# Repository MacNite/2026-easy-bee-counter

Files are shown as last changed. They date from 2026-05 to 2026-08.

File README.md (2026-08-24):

# Bee Counter Redesign — Full Specification
### Single PCB + 3D Printed Housing, reported over BLE to HiveHub

A redesign of the [2019-easy-bee-counter](https://github.com/hydronics2/2019-easy-bee-counter)
by hydronics2: 24 entrance gates, 48 reflective IR sensors read through I²C
port expanders, and an always-on ESP32-C6 doing the counting and reporting
totals over BLE.

> **Status:** the PCB (`PCB_files/easy-bee-counter-2026.kicad_*`) and the
> ESP32-C6 firmware (`Firmware/`) are implemented. The 3D-printed housing
> (Section 5) is the remaining mechanical work.

---

## 1. System Overview

The **ESP32-C6 mini** runs always-on as a dedicated bee counter and advertises
as a connectable BLE peripheral. A HiveHub wakes roughly every 10 minutes,
connects, reads one JSON characteristic of lifetime totals and disconnects,
combining the counts with weight/timestamp data before logging and transmitting.

```
[HiveHub ESP32] ←——— BLE/GATT ———→ [ESP32-C6 mini]
  wakes every ~10 min                always-on, ~15 mA
  RTC, SD, WiFi, scale               bee counting, 3× MCP23017 (I²C)
```

The counter's own I²C bus (`Wire`, silk D4 = GPIO22 SDA / silk D5 = GPIO23 SCL) is used only to reach
the 3× MCP23017 port expanders.

> **The wired HiveScale link is gone.** Earlier revisions ran the C6's second
> I²C controller as a permanent slave at 0x30, serving a register map to a
> HiveScale polling over J1 — and the firmware for it has been removed, because
> HiveHub reads counters over BLE only and dropped its wired client. Sections
> below still describe the J1 connector and its cable, since both are physically
> on the PCB; no firmware brings that bus up, so populating them is optional.

---

## 2. Complete Bill of Materials

### 2.1 Microcontroller

| # | Component | Qty | Notes |
|---|---|-----|---|
| 1 | Seeed XIAO ESP32C6 (Seeed 113991054) | 1 | Always-on bee counter MCU. ~15 mA active, 3.3 V logic, USB-C. Two hardware I²C controllers. **Silk D0..D10 ≠ GPIO numbers** — see `Firmware/include/pins.h` |

### 2.2 I/O Expansion (replaces all 6× 74HC165)

| # | Component | Qty | Notes |
|---|---|-----|---|
| 2 | MCP23017-E/SP (DIP-28) | 3 | 16 inputs each = 48 total. I²C addresses 0x20, 0x21, 0x22 (on bus 0) |

### 2.3 IR Sensors

| # | Component | Qty | Notes |
|---|---|-----|---|
| 3 | QRE1113 or ITR8307 reflectance sensor | 48 | 2 per gate × 24 gates. ITR8307 from LCSC is cheaper (~€0.13 each) |

### 2.4 MOSFETs (IR LED switching)

| # | Component | Qty | Notes |
|---|---|-----|---|
| 4 | IRLB8721PbF N-channel MOSFET (TO-220) | 3 | 3.3 V gate-safe. One per MCP23017: Q1 = LED_BANK_1 (gates 00..07), Q2 = LED_BANK_2 (gates 10..17), Q3 = LED_BANK_3 (gates 20..27). Individually switchable at runtime — see [Power Budget](#6-power-budget) |

### 2.5 Resistors

| # | Component | Qty | Notes |
|---|---|-----|---|
| 5 | 22 Ω bussed SIP resistor (9-pin, 8R) | 3 | IR LED current limiting (2 LEDs in series per gate) |
| 6 | 100 kΩ bussed SIP resistor (9-pin, 8R) | 6 | Sensor pull-up resistors (1 per MCP23017 input, to +3.3 V) |
| 7 | 10 kΩ resistor (through-hole) | 6 | MOSFET gate pull-downs (3×), MCP23017 RESET pull-ups (3×) |
| 8 | 4.7 kΩ resistor (through-hole) | 2 | Bus 0 I²C pull-ups (SDA + SCL to 3.3 V), R4/R5 |

> J1 (the retired HiveScale link) does **not** need on-board pull-ups — those were
> provided by the HiveScale-side I²C network.

### 2.6 Capacitors

| # | Component | Qty | Notes |
|---|---|-----|---|
| 9 | 100 nF ceramic capacitor (through-hole) | 6 | Decoupling, 1 per MCP23017 VDD pin + 3 spare |
| 10 | 10 µF electrolytic capacitor | 1 | Bulk decoupling on 3.3 V rail |

### 2.7 Connectors

| # | Component | Qty | Notes |
|---|---|-----|---|
| 11 | 4-pin JST-PH or screw terminal (I²C bus 1 + GND + 3.3 V) | 1 | Connection cable to HiveScale (J1) |
| 12 | 2-pin screw terminal | 1 | 3.3 V power input from HiveScale |
| 13 | USB-C connector (on C6 mini board) | — | For firmware flashing / serial only |

### 2.8 PCB & Housing

| # | Component | Qty | Notes |
|---|---|-----|---|
| 14 | Custom PCB (single board, black substrate) | 1 | Designed in KiCad (`PCB_files/`). Order black. See Section 4 |
| 15 | 3D printed top baffle / housing | 1 | Carbon-filled PETG or ASA. See Section 5 |
| 16 | M2×6 screws | 8 | PCB to housing standoffs |
| 17 | M2 brass heat-set inserts | 8 | Into 3D printed housing |

---

## 3. Wiring & Connection Map

### 3.1 I²C Buses

This board uses **two separate I²C buses**, one per controller:

**Bus 0 (`Wire`) — MCP23017 master bus.** Silk D4 = GPIO22 = SDA, silk D5 = GPIO23 = SCL. On-board
4.7 kΩ pull-ups (R4/R5) to 3.3 V.

```
XIAO D4 = GPIO22 (SDA) ——+——————+——————+——— 4.7 kΩ ——→ 3.3 V
                        |      |      |
                      MCP1   MCP2   MCP3
                      0x20   0x21   0x22

XIAO D5 = GPIO23 (SCL) ——+——————+——————+——— 4.7 kΩ ——→ 3.3 V
```

**J1 (silk D2 / D3 = GPIO2 / GPIO21) — the retired HiveScale slave bus.** The pads and traces
are on the board, and pull-ups were supplied by the HiveScale side. **No current
firmware brings this controller up**, so the pins stay inputs and populating J1
is optional — see the note in Section 1.

> **Note on the schematic net names:** the schematic labels the master bus nets
> "/SDA" and "/SDC" (a typo for SCL), and the LED-bank nets "/GPIO4" / "/GPIO5"
> / "/GPIO6". Those are just net *names* — physically the LED banks are driven
> from silk D8 = GPIO19, D9 = GPIO20 and D10 = GPIO18. U5 is a Seeed XIAO ESP32C6, whose silk
> numbers are **not** its GPIO numbers; see `Firmware/include/pins.h` for the
> authoritative map.

### 3.2 MCP23017 Wiring (repeat for each of the 3 chips, all on bus 0)

| MCP23017 Pin | Connection | Notes |
|---|---|---|
| 9 (VDD) | 3.3 V | Add 100 nF ceramic cap to GND nearby |
| 10 (VSS) | GND | |
| 12 (SCL) | Bus 0 SCL (silk D5 = GPIO23) | |
| 13 (SDA) | Bus 0 SDA (silk D4 = GPIO22) | |
| 15 (A0) | GND / 3.3 V | Address bit 0 (see table below) |
| 16 (A1) | GND / 3.3 V | Address bit 1 |
| 17 (A2) | GND / 3.3 V | Address bit 2 |
| 18 (RESET) | 3.3 V via 10 kΩ | Tie high; no active reset needed |
| 21–28 (GPA0–7) | IR sensor outputs (inner sensors) | 8 sensors per chip |
| 1–8 (GPB0–7) | IR sensor outputs (outer sensors) | 8 sensors per chip |

**Address configuration:**

| Chip | I²C Address | A2 | A1 | A0 | Gates |
|---|---|----|----|----|----|
| MCP1 (U2) | 0x20 | GND | GND | GND | 00–07 |
| MCP2 (U3) | 0x21 | GND | GND | 3.3 V | 10–17 |
| MCP3 (U4) | 0x22 | GND | 3.3 V | GND | 20–27 |

> Gate tags have gaps (08, 09, 18, 19, 28, 29 are skipped) to keep the
> per-chip pin→gate map clean; there are 24 physical gates indexed 0..23
> internally.

### 3.3 IR Sensor Wiring (per sensor pair, 24× repeated)

Each gate has 2 sensors — one "inner" (towards hive), one "outer" (towards field).

```
QRE1113 pin 1 (Anode / LED+)   ——→ LED string common (+ / 3.3 V via 22 Ω)
QRE1113 pin 2 (Cathode / LED-) ——→ MOSFET Drain (bank rail)
QRE1113 pin 3 (Collector)      ——→ MCP23017 GPIO input pin + 100 kΩ pull-up to 3.3 V
QRE1113 pin 4 (Emitter)        ——→ GND
```

Logical convention in firmware: **sensor reads LOW = beam reflected/blocked
(bee in beam); HIGH = clear or LEDs off.**

### 3.4 MOSFET Wiring (IRLB8721PbF, 3× identical — one per MCP23017)

| IRLB8721 Pin | Connection |
|---|---|
| Gate (pin 1) | Bank enable GPIO from the table below, + 10 kΩ pull-down to GND |
| Drain (pin 2) | IR LED cathode strings for that bank |
| Source (pin 3) | GND |

| FET | Bank | Gates | XIAO silk | GPIO | Schematic net |
|---|---|---|---|---|---|
| Q1 | LED_BANK_1 | 00..07 (U2 @ 0x20) | D8  | GPIO19 | /GPIO4 |
| Q2 | LED_BANK_2 | 10..17 (U3 @ 0x21) | D9  | GPIO20 | /GPIO5 |
| Q3 | LED_BANK_3 | 20..27 (U4 @ 0x22) | D10 | GPIO18 | /GPIO6 |

Driving the gate HIGH turns that bank's IR emitters ON.

### 3.5 HiveScale I²C Connection Cable (bus 1, connector J1)

4-wire cable between HiveScale and bee counter PCB:

| Wire | Signal |
|---|---|
| Red | 3.3 V (from HiveScale to power the C6 + MCP23017s) |
| Black | GND |
| Yellow | SDA (silk D2 = GPIO2) |
| Blue | SCL (silk D3 = GPIO21) |

This cable served the retired wired link and is not needed for a BLE counter;
the board only needs 3.3 V and GND. The MCP23017s live on their own bus and were
never visible over J1 in any case.

---

## 4. PCB Dimensions & Layout

### 4.1 Target Dimensions

Based on standard Langstroth 10-frame hive (476 mm internal entrance width):

| Dimension | Value | Notes |
|---|---|---|
| PCB length | 375 mm | Covers full entrance, leaving margin each side for housing walls |
| PCB width | 40 mm | Enough for components + connector |
| Gate pitch | 15.6 mm | 375 mm / 24 gates. Each gate ~12 mm clear opening + 3.6 mm divider wall |
| Sensor pair spacing | 8 mm | Inner-to-outer sensor distance within one gate |

**Note for European Zander/Deutsch Normal hives:** entrance width is typically 370 mm — adjust PCB length accordingly.

### 4.2 Component Placement

```
[USB-C]  [C6 mini]  [MCP1]  [MCP2]  [MCP3]  [J1 I²C connector]
                    ← electronics zone, left end →

← 24 sensor pairs spread across the remaining length →

Top edge: inner sensors (facing hive interior)
Bottom edge: outer sensors (facing landing board)
```

- ESP32-C6 and MCP23017s cluster at the left end of the PCB
- Sensor pairs run along the full length
- Q1/Q2 MOSFETs near the sensor zone centre with thermal via to bottom copper pour
- Keep the MCP I²C traces short; keep the J1 routing away from the MCP bus
- 100 nF decoupling caps placed directly adjacent to each MCP23017 VDD pin

---

## 5. 3D Printed Housing Specification

### 5.1 Material

| Property | Requirement |
|---|---|
| Material | Carbon-filled PETG (e.g. Prusament PETG CF) or ASA |
| Color | Black (carbon content ensures genuine IR opacity at 950 nm) |
| Layer height | 0.2 mm or finer for gate walls |
| Infill | 40%+ for structural rigidity |

Do NOT use standard black PLA or standard black PETG — most black dyes are IR-transparent at 950 nm. Carbon-filled variants are the exception.

### 5.2 Housing Parts

**Part 1 — Bottom tray** (holds PCB):
- Internal width: PCB width + 2 mm clearance
- Internal length: PCB length + 2 mm clearance
- Depth: 12 mm (enough for tallest through-hole component)
- 4 M2 standoff bosses at corners, 3 mm proud of floor
- Cable exit slot at left end for I²C cable

**Part 2 — Top baffle** (replaces the original second PCB):
- Same footprint as bottom tray
- 24 channel slots cut through, matching sensor pair positions
- Channel slot width: 12 mm (bee passage width)
- Channel slot height (depth of baffle): 10 mm
- Divider wall thickness between channels: 3.6 mm
- Snap or M2 screw attachment to bottom tray (4 points)
- Landing ramp angle on outer face: 15° downward slope toward hive entrance

### 5.3 Gate Geometry

```
Top view of one gate channel:
┌────────────────────────┐
│  ←── 12 mm ──→         │  ← bee passage
│  [outer sensor]         │  ← facing landing board
│          ↕ 8 mm         │
│  [inner sensor]         │  ← facing hive
└────────────────────────┘
     ← 3.6 mm wall →
```

Sensors face upward from the bottom PCB into the channel. The black baffle absorbs any IR not reflected by a bee.

---

## 6. Power Budget

| Component | Current | Count | Total |
|---|---|---|---|
| ESP32-C6 mini (active, BLE advertising) | 15 mA | 1 | 15 mA |
| MCP23017 (active) | 1 mA | 3 | 3 mA |
| Quiescent leakage | — | — | ~1 mA |
| **Electronics subtotal** | | | **~19 mA** |
| IR emitters, all banks lit (peak) | ~20–40 mA/gate | 24 gates | **~0.5–1.0 A** |
| IR emitters, pulsed at 35 % duty (average) | | | **~170–350 mA** |
| HiveScale ESP32 (sleep) | ~0.05 mA | 1 | 0.05 mA |
| HiveScale ESP32 (awake, ~10 min cycle) | 80 mA × 30 s / 600 s | 1 | ~4 mA avg |

**The emitters are the power budget.** Each gate drives two IR LEDs in series
through a 22 Ω ballast off the 3.3 V rail — roughly (3.3 − 2·V_f)/22, i.e. tens
of milliamps per gate — and the pulsed sampler lights all three banks together
for the settle+read window of every 5 ms poll. Everything else on the board
together is under 20 mA, an order of magnitude below. The per-gate figure
depends on the actual LED forward voltage; **measure it on an assembled board**
before sizing a panel or a pack, rather than trusting the range above.

Three things follow, and all three are implemented:

* **Pulsed emitters** (`LedMode::AUTO`, the default since the 2026-06 revision)
  cut the duty cycle from 100 % to ~35 %. Raising `POLL_INTERVAL_MS` lowers it
  proportionally. There is no `CMD_LEDS_OFF` — that was an I²C command on the
  wired link, which no longer exists; the bench overrides are the `-DIR_DEBUG`
  console's `1`/`0`/`a` keys.
* **Night mode** parks the emitters entirely through the hours honey bees do not
  fly, on request from HiveHub. Over an 8–12 h night that is the difference
  between the counter fitting an off-grid budget and not. See
  [`docs/ble-mode.md`](docs/ble-mode.md#night-mode-the-control-characteristic) —
  including why it is *not* implemented as deep sleep.
* **Per-bank enables** switch the three MOSFETs individually, so an entrance
  narrower than 24 gates costs only the banks it uses. Measured on an assembled
  board, at 3.3 V:

  | Banks enabled | Gates counted | Draw |
  |---|---|---|
  | 1 | 8 | ~0.14 A |
  | 2 | 16 | ~0.22 A |
  | 3 (default) | 24 | ~0.30 A |

  Roughly 80 mA per bank on top of a ~60 mA floor. All three are enabled unless
  HiveHub says otherwise (three checkboxes per device in its dashboard), and a
  counter that resets comes back with all three on. It composes with night mode
  rather than competing with it. See
  [`docs/ble-mode.md`](docs/ble-mode.md#emitter-banks-the-other-power-control).

Add solar for indefinite runtime.

---

## 7. BLE Data Handoff

The counter is a connectable BLE peripheral. The canonical definition of the
GATT contract lives in [`docs/ble-mode.md`](docs/ble-mode.md); this is a summary.

- Advertises as `HiveTraffic-AB:12` — the product name suffixed with the last
  two bytes of the counter's own BLE address, so several counters in range are
  distinct rows in a scan list. HiveHub connects by the MAC paired in its
  portal and never matches on the name.
- One service, `8e8b0101-7a1c-4b9e-9a2f-1d6e0b9c1a01`, holding a READ
  measurement characteristic, a READ/WRITE control characteristic (night mode
  and emitter-bank enables) and three OTA characteristics.
- The measurement value is built on read, so it is never a stale snapshot:

```json
{"fw":4,"ver":"0.2.0","uptime_s":1234,"status":15,"num_gates":24,
 "mcps_healthy":3,"total_in":100,"total_out":95,"glitches":2,"idle_s":0}
```

`mcps_healthy` counts MCP23017 port expanders (0..3), not gates — each covers
eight of the 24. `idle_s` is the night-mode countdown, `0` while counting. `fw`
is the wire format's revision, not the image version (`ver`); see
[docs/ble-mode.md](docs/ble-mode.md) for the revision history and the deployment
order it requires.

### Totals only

`total_in` / `total_out` are monotonic lifetime counters; HiveHub differences
consecutive reads into per-interval counts on its server. Nothing on the device
is consumed by being read, so a missed connection cannot lose traffic.

This replaced a register map with interval counters that a `CMD_LATCH` command
zeroed — where a HiveScale that read but failed to latch, or latched but failed
to read, silently lost an interval.

### OTA over BLE

HiveHub relays a new C6 image (downloaded over WiFi) into the counter's OTA
characteristics: BEGIN (size + CRC-32) → DATA frames → END (verify, swap slots,
reboot). Gate counting pauses for the duration. See
[`docs/ble-mode.md`](docs/ble-mode.md).

---

## 8. Firmware Summary

Implemented in `Firmware/` (PlatformIO, `seeed_xiao_esp32c6` env). See
`Firmware/README.md` for build/flash and tuning details.

### ESP32-C6 (bee counter)
- **`Wire` (master):** continuously polls the 3× MCP23017 (~5 ms loop), reading
  all 16 inputs per chip. Read failures are detected, so an expander that goes
  missing has its gates skipped rather than read as "all beams blocked", and is
  re-probed until it comes back.
- **BLE/GATT peripheral:** serves lifetime totals as JSON on read, accepts a
  firmware image on the OTA characteristics, and takes a bounded "stop sensing"
  request plus an emitter-bank enable mask on the control characteristic
  (`src/ble_link.cpp`).
- Per-gate debounce + direction state machine (IDLE → INNER/OUTER_FIRST →
  PAIRED) emits IN/OUT counts; glitches tallied for diagnostics. The logic lives
  in `Firmware/include/gate_logic.h` and is covered by host-side tests
  (`Firmware/test/run_tests.sh`).
- IR banks driven on GPIO19 / silk D8 (bank 1), GPIO20 / silk D9 (bank 2) and
  GPIO18 / silk D10 (bank 3) — one MOSFET per MCP23017. LED mode and per-bank
  enables are both settable from the IR_DEBUG serial console (`1`/`0`/`a` and
  `4`/`5`/`6`), and the bank mask is settable over BLE by HiveHub.
- BLE OTA image receiver (`Update` library) with size + CRC-32 verification
  before the inactive app slot is selected.

### HiveHub ESP32 (data aggregator — lives in the HiveHub firmware, not here)
- On wake: read RTC timestamp, read weight, connect to the counter over BLE and
  read its lifetime totals.
- Difference consecutive totals server-side to get the interval counts.
- Write combined record to SD card; transmit via WiFi if available.
- Optionally relay a firmware update to the C6 over BLE (`update_beecounter`).
- Optionally re-arm the counter's night-mode suspension for the next cycle, and
  re-assert its emitter-bank enable mask.
- Sleep ~10 minutes.

---

## 9. Key Datasheet References

| Component | Key parameter |
|---|---|
| IRLB8721PbF | Vgs(th) max 2.4 V — fully on at 3.3 V ✓ |
| MCP23017 | 3× address pins → up to 8 devices on one bus; 1.7 MHz I²C |
| QRE1113 | 950 nm IR, 20 mA forward current, reflective mode |
| ESP32-C6 | **Two** independent I²C controllers; GPIO map is board-specific (see `pins.h`) |
| DS3231 | ±2 ppm accuracy, integrated TCXO, I²C, backup battery (on HiveScale) |

---

*Document version 2.0 — based on the 2019-easy-bee-counter project by
hydronics2, redesigned for MCP23017 I²C, ESP32-C6 mini, dual independent I²C
buses, OTA-over-I²C, dual-hive addressing, single PCB + 3D printed housing, and
HiveScale integration.*

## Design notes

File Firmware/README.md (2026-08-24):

# HiveTraffic bee counter — ESP32-C6 mini firmware

Firmware for the ESP32-C6 mini bee counter PCB. Continuously polls the 24
entrance gates, detects directional bee crossings, and serves lifetime totals
to [MacNite/HiveHub](https://github.com/MacNite/HiveHub) over BLE/GATT.

There is one build, and it is wireless. Flash it with:

```sh
pio run -t upload
```

The firmware also exposes HiveInside-style connectable BLE OTA characteristics,
which HiveHub drives with its `update_beecounter` command. Image size and CRC-32
are verified before the inactive app slot is selected; see
[`docs/ble-mode.md`](../docs/ble-mode.md) for the framing and the relay.

The image version lives in [`include/version.h`](include/version.h) and is
reported over BLE as the measurement JSON's `ver` field. **Bump it for every
released image** — HiveHub gates an OTA relay on it being newer than what the
counter reports, and uses it afterwards to confirm the update took.

> **The wired HiveScale link has been removed.** Earlier firmware ran the C6's
> second I2C controller as a permanent slave at 0x30, serving a register map
> (totals, `CMD_LATCH` interval counters, per-gate arrays, OTA-over-I2C) to a
> HiveScale polling over J1. HiveHub reads counters over BLE only and dropped
> its wired client, so nothing spoke that protocol anymore. The connector and
> traces are still on the PCB; the firmware simply never brings that controller
> up.

---

## How it works

### Sensing

Each of the 24 gates has two QRE1113 reflective IR sensors:

- **Inner** — toward the hive interior
- **Outer** — toward the outside world

The 48 sensor lines are read through 3 MCP23017 I2C port expanders:

| MCP | I2C addr | Gates | Inner sensors  | Outer sensors  |
| ----- | --- | --- | --- | --- |
| U2 | 0x20 | GATE_00..07 | GPA0..GPA7 | GPB0..GPB7 |
| U3 | 0x21 | GATE_10..17 | GPA0..GPA7 | GPB0..GPB7 |
| U4 | 0x22 | GATE_20..27 | GPA0..GPA7 | GPB0..GPB7 |

The IR emitters are split into three banks driven by IRLB8721 N-channel MOSFETs — one FET per MCP23017 since the 2026-08 hardware revision:

| Bank | Gates | FET | Enable GPIO | XIAO silk | Schematic net |
| ---- | ----- | --- | --- | --- | --- |
| LED_BANK_1 | GATE_00..07 (U2) | Q1 | GPIO19 | D8  | /GPIO4 |
| LED_BANK_2 | GATE_10..17 (U3) | Q2 | GPIO20 | D9  | /GPIO5 |
| LED_BANK_3 | GATE_20..27 (U4) | Q3 | GPIO18 | D10 | /GPIO6 |

The net names `/GPIO4`, `/GPIO5` and `/GPIO6` are labels only — they are **not** physical GPIO4/5/6. Use the Enable GPIO column.

The previous 2-FET build split U3's gates across banks 1 and 2 (00..13 / 14..27); banks now line up 1:1 with the expanders. `pins::IR_LED_BANK_EN[]` maps bank number − 1 to its GPIO, and `gates::TABLE[i].led_bank` gives each gate's bank.

Driving the GPIO HIGH turns the bank's emitters on. In the default `LedMode::AUTO` the emitters are **pulsed**: all three banks are lit together only for the settle + MCP-read window of each poll (~1.75 ms at 100 kHz), then switched off until the next poll. This drops the emitter duty cycle from 100% to roughly 35% at  the default 5 ms poll interval, cutting average emitter current proportionally, with no change to detection behaviour. The IR_DEBUG console's `1` / `0` / `a` keys force steady-on, blackout and pulsed mode respectively for bench work.

Each bank can also be **switched off entirely**, which is a separate control from the LED mode: HiveHub writes an enable bitmask to the control characteristic (`SET_BANKS`, protocol v5) and `include/bank_state.h` decides what is applied. One bank draws ~0.14 A at 3.3 V, two ~0.22 A, three ~0.30 A, so this is the coarsest and most effective power knob on the board — for an entrance narrower than 24 gates, or a supply that will not carry the full one.

All three banks are enabled by default and after any reset; the mask is never persisted, and HiveHub re-asserts it every upload cycle. A mask of `0` is refused rather than applied. Gates on a dark bank are **skipped**, not read as "clear": an unpowered QRE1113 is a bare phototransistor under a 100 kΩ pull-up, and direct sun into the entrance can pull one low. The expander itself is still read and health-checked, so `mcps_healthy` keeps its meaning. The IR_DEBUG console's `4` / `5` / `6` keys toggle banks 1/2/3 for bench work.

### Counting

Each gate is a small state machine:

```
   IDLE ──Inner blocked──▶ INNER_FIRST ──Outer blocked──▶  count OUT
        ──Outer blocked──▶ OUTER_FIRST ──Inner blocked──▶  count IN
                          (within 2 s, else timeout)
```

After a count, the gate waits in `PAIRED` until both sensors are clear,
then returns to `IDLE`. Glitches (both blocked simultaneously, or only one
ever blocks before timeout) are counted and reported as the JSON `glitches` field for diagnostics.

### One I2C bus

The MCP23017s sit on `Wire` (GPIO22 / silk D4 = SDA, GPIO23 / silk D5 = SCL), with the on-board 4.7 kΩ
pull-ups R4/R5. The loop polls them on a ~5 ms cadence and nothing else shares
the bus, so there is no arbitration to think about.

The PCB also routes a second bus to J1 on silk D2/D3 (GPIO2/GPIO21) for the retired HiveScale
link. The firmware never initialises that controller, so those pins stay inputs.

### Reporting

Counting produces **lifetime totals only**. HiveHub connects once per upload
cycle, reads one JSON characteristic and disconnects; it derives each interval by
differencing consecutive reads on its server. That is why there is no latch, no
reset and no per-interval state on the device — a missed connection cannot lose
traffic, because nothing is ever consumed by being read.

See [`docs/ble-mode.md`](../docs/ble-mode.md) for the GATT contract, the JSON
fields and the OTA framing, and `include/counter_protocol.h` for the status
bitfield and OTA state codes shared between `main.cpp` and `ble_link.cpp`.

---

## Building & flashing

```bash
pio run               # build
pio run -t upload     # flash via USB
pio device monitor    # 115200 baud serial output
```

PlatformIO target is `seeed_xiao_esp32c6`. U5 on this PCB is a **Seeed XIAO
ESP32C6** (Seeed part 113991054), not a bare ESP32-C6-MINI-1, so this is the
board profile that matches the hardware: it declares the module's 4 MB flash
(the earlier `esp32-c6-devkitc-1` profile declared 8 MB) and pulls in the
`XIAO_ESP32C6` variant. That variant defines the `D0..D10` aliases but does
*not* enable Arduino pin remapping, so the raw GPIO numbers in `pins.h` are
still correct as written. Do not read the board's silk numbers as GPIO numbers —
they differ (silk D4 is GPIO22). USB CDC is enabled in `platformio.ini`, so
`Serial` output comes out over USB without an external UART bridge.

The build uses `partitions_4mb_ota_no_fs.csv` — two 2 MB app slots so BLE OTA
can write the inactive one. The table sums to exactly 4 MB, which is the flash
the XIAO board profile declares. A counter still running a pre-BLE image was
flashed with a single-app layout and **must be updated once over USB**; OTA
cannot migrate a partition table.

### Build artifacts

[`rename_firmware.py`](rename_firmware.py) (wired in as a `pre:` extra script)
names the products after the board and the version from `include/version.h`
instead of the generic `firmware.bin`:

| Environment | Artifact in `.pio/build/<env>/` |
| --- | --- |
| `seeed_xiao_esp32c6` | `hivetraffic_esp32-c6_<version>.bin` |

That name is what makes an image self-describing to HiveHub. Drop the `.bin`
into the dashboard's **Upload firmware** form and it reads the filename to
pre-select target *HiveTraffic counter* and pre-fill the Version field — the
board is fixed at `esp32-c6`, and the backend refuses to publish a release whose
board disagrees with its filename, so a cross-architecture image can never be
relayed to a counter. Upload this file **as-is**: it is the application-only
image, which is what the counter's OTA writes into its inactive app slot, not a
merged factory image.

Because the naming is a contract with HiveHub, the board token and layout have
to stay in sync with HiveHub's `rename_firmware.py`, `server/firmware.py`
(`board_from_filename`, `BEECOUNTER_BOARDS`) and the dashboard's filename
parsing. The header comment in `rename_firmware.py` lists them.

Should a variant build ever be needed again, stamp it after the version rather
than into the board token: `0.1.0-something` is what shows up in the pre-filled
Version field, so it is hard to publish by mistake, and HiveHub compares
versions component-wise with non-digits stripped — such a build ties with the
production image of the same version and can never be relayed over it.
`rename_firmware.py` already falls back to `-<env name>` for any environment it
does not know.

---

## USB IR-sensor debug console (bench bring-up)

For initial testing of the IR sensors over USB — with no HiveScale / I2C master
attached — there is an interactive serial console in `main.cpp`. It has no
environment of its own; compile it into the production build on demand:

```bash
PLATFORMIO_BUILD_FLAGS=-DIR_DEBUG pio run -t upload
pio device monitor    # 115200 baud
```

That build is identical to production but compiles in the console (gated behind
`-DIR_DEBUG`, so it is **never** in the normal firmware). Note that the artifact
keeps the production filename, so do not upload one of these to HiveHub.
Press a single key in the serial monitor:

| Key | Action |
| --- | --- |
| `r` | Read & print all 24 gates' inner/outer beam state once |
| `s` | Toggle continuous streaming (~200 ms) |
| `1` | Force IR LEDs ON (steady) |
| `0` | Force IR LEDs OFF |
| `a` | IR LEDs AUTO (normal pulsed mode) |
| `n` | Arm / clear a 60 s night-mode suspension (press again to resume) |
| `4` | Toggle emitter bank 1 (GATE_00..07) |
| `5` | Toggle emitter bank 2 (GATE_10..17) |
| `6` | Toggle emitter bank 3 (GATE_20..27) |
| `h` | Show the command list |

The bank keys are `4`/`5`/`6` because the schematic labels those rails `/GPIO4`,
`/GPIO5` and `/GPIO6` — misleading net names (they are physically GPIO19/20/18)
but the ones silkscreened next to the FETs.

Each reading lists the raw MCP23017 port words, the current bank mask, plus a
per-gate `BLOCK`/`clear` line for the inner and outer sensor. A gate whose bank
is switched off prints `<bank disabled>` rather than a beam state. The emitters are pulsed on for every read
regardless of the LED mode, so the readout is always valid. Wave a finger or a
bee through a gate and you should see that gate's `inner`/`outer` flip to
`BLOCK`.

---

## Tuning

All the knobs are at the top of `src/main.cpp`:

| Constant | Default | Effect |
| --- | --- | --- |
| `POLL_INTERVAL_MS` | 5 | How often the MCP23017s are polled for crossings |
| `SENSOR_DEBOUNCE_MS` | 5 | Minimum time a new sensor value must persist before it is accepted |
| `SENSOR_DEBOUNCE_SAMPLES` | 2 | Consecutive polls that must agree before a change is accepted |
| `GATE_PAIRING_WINDOW_MS`  | 2000 | Max time between inner/outer trip for a directional count |
| `SENSOR_STUCK_MS` | 30000 | After this many ms continuously blocked, fault flag is raised |
| `MCP_FAIL_THRESHOLD` | 3 | Consecutive failed reads before a chip is declared unhealthy  |
| `MCP_RETRY_INTERVAL_MS` | 5000 | How often an unhealthy chip is re-probed |
| `I2C_MASTER_HZ` | 400000  | MCP bus clock; reduces every pulsed sample's IR-on and CPU-wait time |
| `LED_SETTLE_US` | 250 | IR emitter settle time before each pulsed read. Lower = less power but risks reading stale "clear" levels if shorter than the real phototransistor settle time. |

If your hive has unusually long entrance tunnels or slow-moving bees, raise
`GATE_PAIRING_WINDOW_MS`.

### The debounce rule

A sensor change is accepted only once the new value has been seen on
`SENSOR_DEBOUNCE_SAMPLES` **consecutive** polls *and* has persisted for at least
`SENSOR_DEBOUNCE_MS`. Both halves matter, and they interact with
`POLL_INTERVAL_MS`:

- A `SENSOR_DEBOUNCE_MS` shorter than one poll period cannot reject anything —
  the first differing sample already satisfies it. At the 5 ms poll rate the
  sample count is the half that actually does the work.
- `SENSOR_DEBOUNCE_SAMPLES = 2` is the practical ceiling. A bee crossing at
  ~25 cm/s dwells ~12 ms in a 3 mm beam, i.e. 2-3 samples; requiring three
  agreeing samples (~10 ms) would start dropping real crossings. Two rejects a
  single corrupted or noisy word while accepting a genuine block ~5 ms after it
  appears.

So if you see noise on `glitches`, do **not** simply raise
`SENSOR_DEBOUNCE_SAMPLES` — poll faster first (lower `POLL_INTERVAL_MS`, at the
cost of emitter duty cycle) so a longer debounce still fits inside the dwell.

The rules live in `include/gate_logic.h` and are covered by the host-side tests
described under [Tests](#tests).

### Expander health

Each MCP23017 is tracked at runtime rather than only at boot:

- A chip that fails `MCP_FAIL_THRESHOLD` consecutive reads is marked unhealthy,
  its `STATUS_MCP_U*_OK` status bit is cleared, and its eight gates are reset
  and skipped. Gates are skipped from the *first* failed read — a failed I2C
  transaction reads as `0x0000`, which is indistinguishable from "all 16 beams
  blocked", so it must never reach the state machine.
- An unhealthy chip (including one missing at boot) is re-probed every
  `MCP_RETRY_INTERVAL_MS`, with the emitters dark so a probe never lengthens the
  LED pulse. On recovery its gates are reset and its status bit is set again.
- `mcps_healthy` in the BLE telemetry reflects this live state — it counts
  expanders (0..3), not gates. It was called `gates_healthy` before protocol v3.

---

## Tests

Several pure headers carry logic that is worth testing without hardware, so each
is deliberately free of Arduino, I2C and NimBLE dependencies and all of them run
on a host compiler:

```
./test/run_tests.sh
```

No ESP32, no MCP23017 and no bee required.

* **`include/gate_logic.h`** — sensor debounce, the per-gate direction state
  machine and the saturating counters. The suite covers single-sample spikes,
  alternating noise, simultaneous transitions, minimum-dwell and repeated
  crossings, pairing-window expiry, stuck sensors, `millis()` rollover and
  counter saturation. Run it before pushing a change to the timing rules: the
  failure it was written to catch (a debounce that accepted the first differing
  sample) is invisible in a code read and effectively untestable on a live hive.
* **`include/measurement_json.h`** — the exact bytes of the BLE measurement
  characteristic, which is HiveHub's half of a two-repo contract. The suite
  pins the field names, checks that `uptime_s` and `glitches` really do carry
  values past their old 16-bit ceilings, and measures the saturated worst-case
  document against the buffer it has to fit in. Run it before changing any
  reported field — and bump `PROTOCOL_VERSION` and update HiveHub's parser in
  the same revision when you do (see `docs/ble-mode.md`).
* **`include/idle_state.h`** — the night-mode suspension deadline. The suite
  covers clamping an over-long request, the `millis()` rollover, and the case
  that matters most in the field: HiveHub stopping re-arming, after which the
  counter has to free itself. A counter stuck suspended emits perfectly
  well-formed documents full of zeros, which is indistinguishable from a spell
  of bad weather until someone reads a week of totals — so none of this is
  something a bench session would catch.
* **`include/bank_state.h`** — the emitter-bank enable mask. Every mistake it
  can make is silent: a bank that should be on but is off produces a
  permanently flat third of the totals, which reads exactly like a dead FET,
  and a bank that should be off but is on quietly costs ~80 mA on a supply
  sized without it. The suite pins the refusal of an all-off mask, the
  one-based bank numbering that `gates::TABLE[].led_bank` depends on, and the
  masking of bits above the last physical bank.
* **`include/device_name.h`** — the advertised BLE name, `HiveTraffic-AB:12`.
  The suffix is the last two bytes of the counter's own address, and every way
  of getting it wrong produces a name that still looks like a name while
  pointing at the wrong device: the suite pins the byte order (NimBLE stores
  addresses little-endian, so the two bytes are `val[1]`, `val[0]`), the
  two-digit uppercase rendering a scanner matches against, the fallback when no
  address can be read, and the refusal to truncate into a buffer that cannot
  hold the whole name.

Everything hardware-facing stays in `src/main.cpp` and is still verified on the
bench with the IR-sensor console above.

---

## Wiring sanity check

When you power the board for the first time you should see, on the serial
monitor:

```
==============================================
Easy Bee Counter 2026 — firmware booting (BLE/GATT link)
==============================================
[MCP] U2 (gates 00..07) @ 0x20: OK
[MCP] U3 (gates 10..17) @ 0x21: OK
[MCP] U4 (gates 20..27) @ 0x22: OK
[BLE] HiveTraffic-AB:12 0.3.1 advertising for HiveHub
[SETUP] Entering normal counting loop (pulsed IR)
```

A chip that shows `NOT FOUND` is not written off: the firmware re-probes it
every `MCP_RETRY_INTERVAL_MS` and logs `recovered` if it starts answering, so a
marginal connection can come back without a power cycle. Its eight gates are
skipped (not counted as blocked) while it is down. If it never recovers, check:

- That the A0/A1/A2 strap pins of that chip are connected as the schematic
  says (U2=0x20: all GND; U3=0x21: A0→3V3; U4=0x22: A1→3V3).
- That the 4.7 k pull-ups R4/R5 are populated.
- That the chip's VDD pin 9 is at 3.3 V and VSS pin 10 is at GND.

After boot, breaking a gate's beam (e.g. with a piece of paper) should
trigger a serial counter increase on the next 30 s status dump.

The final boot line now reads:

```
[SETUP] Entering normal counting loop (pulsed IR)
```

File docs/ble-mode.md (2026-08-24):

# Wireless HiveHub mode (BLE/GATT)

BLE/GATT is the counter's only transport, and this is the only build. It pairs
with the wireless **HiveTraffic counter** client in
[MacNite/HiveHub](https://github.com/MacNite/HiveHub); the wired I2C link, and
HiveHub's client for it, have both been removed.

## Build and pair

```sh
cd Firmware
pio run
pio run -t upload
```

Build HiveHub with `ENABLE_WIRELESS_BEECOUNTER=1`, then pair the counter's BLE
MAC as a **HiveTraffic counter** in HiveHub's provisioning portal. The device
advertises as `HiveTraffic-AB:12`, where the four hex digits are the last two
bytes of that MAC — so the scan list tells you which counter you are pairing.
HiveHub itself connects by the paired MAC and never matches on the name.

## HiveHub GATT contract

| Item | Value |
| --- | --- |
| Service | `8e8b0101-7a1c-4b9e-9a2f-1d6e0b9c1a01` |
| Measurement characteristic | `8e8b0102-7a1c-4b9e-9a2f-1d6e0b9c1a01` |
| Properties | READ |
| Control characteristic (night mode + emitter banks) | `8e8b0103-7a1c-4b9e-9a2f-1d6e0b9c1a01` |
| Properties | READ, WRITE |

The value is generated when HiveHub reads it, so it contains current lifetime
totals rather than a periodically cached snapshot:

```json
{"fw":5,"ver":"0.3.0","uptime_s":1234,"status":15,"num_gates":24,"mcps_healthy":3,"total_in":100,"total_out":95,"glitches":2,"idle_s":0,"banks":7}
```

| Field | Type | Meaning |
| --- | --- | --- |
| `fw` | uint8 | Revision of *this document's* format (`PROTOCOL_VERSION`), currently 5 |
| `ver` | string | Image version from `include/version.h`, `MAJOR.MINOR.PATCH` |
| `uptime_s` | uint32 | Seconds since boot |
| `status` | uint8 | Status bitfield, see `include/counter_protocol.h` |
| `num_gates` | uint8 | Gates wired to this counter (24) |
| `mcps_healthy` | uint8 | MCP23017 expanders currently answering, 0..3 — **not** gates |
| `total_in` / `total_out` | uint32 | Monotonic lifetime totals, saturating |
| `glitches` | uint32 | Diagnostic tally of ambiguous/aborted pairings, saturating |
| `idle_s` | uint32 | Seconds of night-mode suspension still to run; `0` while counting |
| `banks` | uint8 | Bitmask of enabled emitter banks (MOSFETs): bit 0 = gates 00..07, bit 1 = 10..17, bit 2 = 20..27. `7` unless banks have been switched off |

The field names, UUIDs, and integer types match HiveHub's
`firmware/include/bee_counter_wire.h` parser, which reads `fw` first and
accepts both this revision and the previous one. The firmware deliberately
emits only the fields in HiveHub's documented contract.

The exact bytes are produced by `include/measurement_json.h` and pinned by
`test/test_measurement_json/`, which runs on a host compiler — see
[Revision history](#revision-history) before changing any of them.

`fw` and `ver` are **not** the same thing and neither replaces the other:

* `fw` is `beecounter_proto::PROTOCOL_VERSION` — the wire format's revision.
* `ver` is the image version from `include/version.h`, in `MAJOR.MINOR.PATCH`
  form. HiveHub compares it with `parse_version` to decide whether an OTA relay
  is worth running, and re-reads it after the counter reboots to confirm the
  update actually took. A counter that reports no `ver` (firmware older than
  this field) is never blocked from an update — there is simply nothing to
  compare against.

Bump `HIVETRAFFIC_FW_VERSION` in `Firmware/include/version.h` for every released
image, or HiveHub will refuse the relay as "not newer".

## Advertising layout

The name is carried in the **scan response**, not the advertisement:

| PDU | Contents | Bytes |
| --- | --- | --- |
| Advertisement | flags + the 128-bit service UUID | 21 / 31 |
| Scan response | complete local name `HiveTraffic-AB:12` | 19 / 31 |

All three elements together are 40 bytes and do not fit one legacy 31-byte
advertising PDU. NimBLE 2.x defaults scan response off and does not relocate an
overflowing name on its own, so they are split explicitly in `begin()`. Keep
them split when adding anything else to the advertisement — a counter that fails
to advertise is invisible to the measurement read *and* to the OTA relay, which
locates it by scan before connecting.

### The name and its address suffix

The advertised name is not the bare product name: it is `HiveTraffic-AB:12`,
where the suffix is the last two bytes of the counter's own BLE address,
rendered the way a scanner prints them. Several counters in range therefore
appear as distinct rows, and a row is matched to a physical box by reading the
tail of the address shown beside it — rather than by opening a detail view for
each identical `BeeCounter` entry, which is what this replaced.

NimBLE advertises with its default public address, which on the ESP32-C6 is the
factory eFuse MAC. The suffix is therefore unique per unit, stable across
reboots, reflashes and OTA updates, and needs nothing provisioned per device.
The same string is written to the GAP Device Name characteristic, so a client
that connects and reads it agrees with the scan list.

Only the last two bytes are in the name, so two counters whose addresses share
them are not told apart by it — 1 in 65536 for factory addresses, and the
address itself still distinguishes them. If the address cannot be read at all,
the bare `HiveTraffic` is advertised rather than nothing.

None of this is on the wire contract: `fw` does not move, HiveHub connects by
the paired MAC, and no client matches on the name. The string is built by
`include/device_name.h` and pinned by `test/test_device_name/`.

## Counting and interval semantics

`total_in` and `total_out` are monotonic lifetime counters until reboot or
32-bit saturation. HiveHub differences consecutive totals on its server to
calculate intervals. The BLE client does not latch or reset the counter after
a read, so an unavailable upload cycle does not discard traffic.

The saturation is genuine: both totals stop at `4294967295` rather than wrapping
to zero, and `status` bit `0x40` is raised when a counter reaches that value. A
wrap would be indistinguishable from a reboot to a client that only sees the
totals, and would make one interval's difference enormously negative. The same
applies to `glitches`, which is also 32-bit and also saturates — a wrapping
diagnostic counter can make a badly unhealthy device look like it has *fewer*
glitches than it did on the previous read, and the 16-bit ceiling it used to pin
at is reachable in a day on a genuinely noisy device.

`uptime_s` is seconds since boot, and its only real job is to show that the
device restarted when you did not expect it to. It is 32-bit; the practical
limit is not the field but `millis()`, which rolls over after about 49.7 days,
so the value restarts then too. (Before protocol v3 the field was 16-bit and
clamped at 65535 — 18 h 12 min — which meant an always-on counter reported one
constant number for its entire deployment and could not do that job at all.)

`mcps_healthy` counts the MCP23017 expanders currently answering on the I2C bus,
so it ranges 0..3 while `num_gates` is 24; each healthy chip covers eight gates.
**It is not a count of working gates** — the name it carried before protocol v3,
`gates_healthy`, invited exactly that reading, and a healthy device reporting
`3` alongside `num_gates: 24` looked almost entirely broken.

It reflects live health, not what was found at boot: a chip that stops answering
drops out of the count within a few polls (and clears its `STATUS_MCP_U*_OK`
status bit), and one that recovers — or that was absent at boot and later
appears — is counted again after the firmware's periodic re-probe. Gates on an
unhealthy chip are skipped entirely rather than sampled, so they contribute
neither counts nor glitches while it is down. Any consumer treating the value as
fixed after boot is wrong regardless of which name it reads.

This is why the device keeps no interval state at all. The retired wired
protocol had interval registers a `CMD_LATCH` command consumed, which meant a
HiveScale that read but failed to latch — or latched but failed to read —
silently lost an interval. Differencing totals cannot lose anything: a read is
not a consumption.

## Power and performance choices

* Measurement JSON uses a fixed 240-byte stack buffer, without ArduinoJson or
  `String` heap churn.
* Telemetry is serialized only on a GATT read, not every two seconds.
* The measurement path remains read-only; OTA uses three separate
  HiveInside-compatible characteristics and does no periodic work when idle.
* Advertising runs once per second. HiveHub connects by configured MAC roughly
  once per upload cycle, so fast advertising only adds radio wakeups. A
  connection can take about one second longer in the worst case.
* The MCP23017 bus runs at 400 kHz, reducing CPU wait and the time all 48 IR
  emitters remain powered during every sample. The 5 ms cadence is unchanged.

The IR emitters still dominate power use. Do not increase the poll period
without validating missed-crossing rates on assembled entrance hardware.

## Compatibility limits

* Lifetime totals are held in RAM. HiveHub recognizes a backwards total after
  reboot as a reset, but traffic before the first successful post-reboot read
  cannot be reconstructed.
* Reflective sensors require continuous sampling, so **uninterrupted** counting
  and sleep are incompatible. Night mode (below) is the deliberate exception:
  it stops counting on purpose, during hours when there is nothing to count, and
  says so in the document.

## Night mode (the control characteristic)

Sampling 24 gates costs almost nothing in CPU and almost everything in emitter
current: 48 IR LEDs in 24 series pairs behind 22 R ballast, all lit together for
the settle+read window of every 5 ms poll. That is roughly 0.5-1.0 A peak and,
at the ~35 % duty the pulsed sampler runs, an average draw an order of magnitude
above the ~18 mA the C6 and the three expanders draw between them. On an
off-grid hive it is the entire power budget.

European honey bees are diurnal. Flight requires light — they will not fly in
darkness at any temperature — and stops below roughly 10 C regardless, so the
emitters spend every night burning the largest item in the budget to count
nothing. Night mode parks them.

### What the counter knows, and what it does not

**The counter never learns what time it is.** It has no RTC, no NVS and no
network. HiveHub has all three (NTP plus a DS3231 at +/-2 ppm) and owns the
schedule; the counter is told only *how long* to stay quiet:

| Frame | Bytes |
| --- | --- |
| SET_IDLE | `0x01 + duration_s(4 LE)` |
| RESUME | `0x02` |
| SET_BANKS | `0x03 + bank_mask(1)` — see [Emitter banks](#emitter-banks-the-other-power-control) |
| Read-back | `state(1) + remaining_s(4 LE) + bank_mask(1)`, state `0x00` sensing / `0x01` idle |

A `SET_IDLE` of `0` means the same thing as `RESUME`, so HiveHub can cancel on a
connection it already has without a second opcode.

This is the whole design, and every property that matters falls out of it:

* **It expires.** A HiveHub that crashes, loses power or is carried off cannot
  leave a counter blind — the deadline runs out and sensing resumes. A stored
  20:00-06:00 schedule would stay wrong until someone walked to the hive.
* **It is bounded.** `MAX_IDLE_SECONDS` is one hour, several times HiveHub's
  default 10-minute cycle. HiveHub re-arms every cycle for as long as its night
  window lasts, so no single request ever has to cover a whole night, and the
  counter's own clock only has to be right for one cycle at a time.
* **A longer request is clamped, not refused.** Refusing would leave the
  emitters running all night because one field was too large.
* **It is never persisted.** Any reset — brownout, watchdog, OTA reboot — comes
  back counting.
* **It is refused during an OTA.** A transfer already parks the emitters and
  pauses polling; the two mechanisms have no opinion about each other.

The deadline arithmetic lives in `include/idle_state.h`, free of Arduino, and is
pinned by `test/test_idle_state/` — including the `millis()` rollover and the
"HiveHub stopped re-arming" case, neither of which is practical to reproduce on
a hive.

### Why not deep sleep

Deep sleep was the obvious implementation and is the wrong one. It buys the
residual ~18 mA on top of what parking the emitters already saves — under 10 %
of the total — and costs:

* the counter is **invisible** for 8-12 h: no measurement read, so every night
  row carries `bee_counter.ok=false`;
* **no OTA**, which contradicts the standing advice to relay firmware at night
  (see HiveHub's `docs/hivetraffic-bee-counter.md`) because a transfer costs
  counted bees;
* **no cancelling** it once entered, however wrong the schedule turns out to be;
* the lifetime totals live in RAM and would need moving into RTC memory;
* `uptime_s` resets every morning, so every day looks like an unexplained reboot
  — the one thing that field exists to reveal;
* and the ESP32-C6's deep-sleep timer runs off the internal ~150 kHz RC
  oscillator, which is strongly temperature-dependent. Over an 8-12 h sleep in a
  hive that swings 10-25 C overnight, expect several minutes of drift and up to
  ~30 minutes worst case. Re-arming a short window from HiveHub's DS3231 instead
  means nothing accumulates and the worst-case error is one cycle.

Staying awake keeps the counter readable, updatable and cancellable all night,
for a few percent of the saving. If the residual current ever does matter, deep
sleep belongs behind its own opcode, with the totals moved to `RTC_DATA_ATTR`
first.

### What a night looks like in the data

`total_in` / `total_out` are frozen for the duration, so the differenced
interval across the suspension is genuinely zero rather than missing. The
`STATUS_NIGHT_IDLE` bit (`0x80`) and the `idle_s` countdown are what separate
that from a counter whose emitter FETs have died — which produces an identical
row of zeros and is otherwise indistinguishable until someone reads a week of
totals.

## Emitter banks (the other power control)

Night mode answers *when should the counter stop?* This answers *how much of
the counter should exist at all?*

Since the 2026-08 hardware revision the 48 IR emitters are split across three
IRLB8721 MOSFETs, one per MCP23017, so each third of the entrance is
independently switchable:

| Bank | Bit | Expander | Gates |
| --- | --- | --- | --- |
| 1 | `0x01` | U2 @ 0x20 | 00..07 |
| 2 | `0x02` | U3 @ 0x21 | 10..17 |
| 3 | `0x04` | U4 @ 0x22 | 20..27 |

Measured on the 3.3 V rail with the pulsed sampler at its defaults:

| Banks enabled | Gates counted | Draw @ 3.3 V |
| --- | --- | --- |
| 1 | 8 | ~0.14 A |
| 2 | 16 | ~0.22 A |
| 3 (default) | 24 | ~0.30 A |

That is roughly 80 mA per bank on top of a ~60 mA floor — dropping one bank
saves about as much current as a quarter of a night of night mode, except it
applies around the clock. The two features compose: a counter can be running on
one bank *and* be suspended, and the numbers multiply rather than compete.

Use it when the entrance is physically narrower than 24 gates, when a hive is
being run with part of its entrance closed, or when an off-grid supply will not
carry the full board. It is a **configuration**, not a schedule — HiveHub's
dashboard exposes it as three checkboxes per device, all ticked by default.

### The rules, and why each one exists

* **All three enabled is the default and the post-reset state.** Nothing about
  this is persisted on the counter, exactly as with night mode: a brownout, a
  watchdog or an OTA reboot comes back counting all 24 gates, and HiveHub
  re-asserts the mask on its next upload cycle. The worst case is one cycle of
  drawing more current than was asked for — never a counter that boots blind on
  two thirds of its entrance because of a write it received a month ago.
* **A mask of `0` is refused, not applied.** The counter keeps whatever it had
  and says so on the serial log. Blinding a counter entirely is not a
  configuration anyone needs — a counter that should count nothing is unpaired
  — and accepting it would let one corrupted byte stop counting until someone
  walks to the hive. Same reasoning as `start == end` disabling the night
  window rather than covering the whole day.
* **Bits above bank 3 are ignored.** A four-FET board's mask arriving here must
  not conjure a bank whose GPIO does not exist. A mask of *only* phantom bits is
  therefore a zero mask, and is refused as one.
* **Gates on a dark bank are skipped, not read as "clear".** An unpowered
  QRE1113 is a bare phototransistor under a 100 k pull-up, and direct sun into a
  hive entrance can pull one low. Feeding those readings to the state machine
  would invent crossings on gates the operator deliberately switched off.
* **The expander is still read and still health-checked.** `mcps_healthy` keeps
  meaning "MCP23017s answering on the I²C bus", so a chip that dies while its
  bank is off is still visible. The read costs about half a millisecond and no
  measurable current; the emitters are what the feature is about.
* **`num_gates` keeps reporting 24.** It describes what is *wired*, which has
  not changed. Active gates are `popcount(banks) * 8`, derived by the consumer,
  so the meaning of every stored reading stays fixed.
* **It is accepted during an OTA**, where `SET_IDLE` is refused. A suspension
  armed under a transfer would outlive a reboot it cannot survive; a bank mask
  is re-asserted every cycle anyway, and the emitters are dark for the transfer
  either way.

### What a switched-off bank looks like in the data

A third of the entrance stops contributing to `total_in` / `total_out`
permanently — which is character for character what a dead emitter FET produces.
`banks` is the only thing that separates them, which is why it is emitted on
every document including the `7` of a counter nobody has reconfigured: a field
that appeared only when it was interesting would make "all banks on" and
"counter too old to say" the same absence.

On the bench the `-DIR_DEBUG` console toggles banks live with the `4`, `5` and
`6` keys (named for the schematic's `/GPIO4`, `/GPIO5`, `/GPIO6` FET rails), and
prints the mask on every readout.

## Firmware update over connectable BLE

HiveTraffic advertises connectably at all times for measurements and updates.
Its framing matches HiveInside, with a HiveTraffic UUID base, so a HiveHub relay
can reuse the HiveInside streaming state machine.

| Characteristic | UUID | Properties |
| --- | --- | --- |
| OTA control | `8e8b0110-7a1c-4b9e-9a2f-1d6e0b9c1a01` | WRITE |
| OTA data | `8e8b0111-7a1c-4b9e-9a2f-1d6e0b9c1a01` | WRITE, WRITE_NR |
| OTA status | `8e8b0113-7a1c-4b9e-9a2f-1d6e0b9c1a01` | READ, NOTIFY |

### Frames

* BEGIN: `0x01 + image_size(4 LE) + crc32(4 LE)`.
* DATA: raw application-image bytes in order. Writes with response provide
  flash-level flow control.
* END: `0x03`; accepted only after exact size and CRC verification.
* ABORT: `0x04`; discards the partial inactive-slot write.
* STATUS: `state(1) + received(4 LE) + error(1)`. States are idle `0x00`,
  receiving `0x01`, done `0x02`, or errors `0x10` through `0x15`.

`received` is live progress, in both of the ways a client can ask for it:

* a **read** is answered from an `onRead` callback that builds the value at that
  instant, so a polling client always sees the current byte count;
* **subscribers** are notified on every state change (BEGIN, END, ABORT, errors)
  and, during the transfer, at most once every 250 ms.

The throttle is deliberately time-based rather than every-N-kilobytes: it bounds
the notification rate to four per second whatever the MTU, connection interval
or image size, where a byte threshold ties the rate to throughput and turns a
fast link into a notify storm competing with the DATA writes it reports on.

(Until protocol v3's firmware, `publishOtaStatus()` ran only on BEGIN, END,
ABORT and errors. DATA writes advanced the counter without refreshing the
characteristic, so a read mid-transfer returned the value BEGIN left there —
normally zero — and subscribers heard nothing in between. Nothing depended on
it: the HiveHub relay gates on `STATUS = DONE` and counts the bytes it sends
itself.)

CRC is standard IEEE/zlib CRC-32 (`0xEDB88320`, initial/final XOR
`0xFFFFFFFF`). Upload PlatformIO's application-only `firmware.bin`, not a
merged factory image. `Update.begin()` rejects an image that
cannot fit the inactive partition.

Gate polling pauses and the emitters remain off during transfer. A disconnect
aborts the partial write and immediately allows counting to resume. DONE remains
readable for 1.5 seconds after verification, then the ESP32-C6 reboots. A bad
size, CRC, interrupted link, or ABORT leaves the running image bootable.

### The HiveHub relay

HiveHub implements this as the `update_beecounter` command. Its HiveInside
HTTPS-to-GATT relay is parameterised over a `gattota::Target` descriptor
(service + control/data/status UUIDs), so HiveTraffic reuses the same streaming
state machine with the `8e8b01xx` UUIDs above:

1. Upload a `beecounter` firmware release (target `beecounter`, board
   `esp32-c6`) to the backend.
2. Press **Relay to counter** in the dashboard, or
   `POST /api/v1/devices/{id}/commands/update-beecounter?slot=N`.
3. HiveHub resolves hive `N`'s paired `beecounter` MAC from its hive registry,
   streams the image straight from the HTTPS download into the DATA
   characteristic, and requires `STATUS = DONE` before reporting success.
4. The counter reboots and re-advertises; the next measurement read picks up the
   new `ver`, which is what confirms the update took.

The build already names the image so the backend can stamp the board —
`hivetraffic_esp32-c6_<version>.bin`. Upload it as produced. See
`Firmware/rename_firmware.py` for the naming contract.

What each token actually does on the HiveHub side, verified against its code
rather than assumed:

* `esp32-c6` is the load-bearing one. `server/firmware.py::board_from_filename`
  reads the board out of the filename, and `resolve_release_board` **refuses**
  the upload if the declared board disagrees with it, or if the filename names a
  board that is not valid for the target. That is what stops a
  cross-architecture image from ever reaching a counter.
* `hivetraffic` is a **convenience for the dashboard's upload form**, not a
  server-side routing rule. `targetFromFilename` in
  `server/dashboard/assets/views.js` matches `/hivetraffic|beecounter/` and
  pre-selects target *HiveTraffic counter*. The backend never infers the target
  from the filename — `target` is an explicit form field — so an image uploaded
  under any name lands wherever the operator (or the API caller) set it.
* The trailing dotted token pre-fills the Version field
  (`versionFromFilename`).

Because that dashboard regex matches `beecounter` too, an image named
`beecounter_esp32-c6_<version>.bin` is *also* accepted and targeted correctly —
it is not silently mis-targeted. Both prefixes work; `hivetraffic` is the one
the build produces and the one to use.

The service has no authentication. Deployment therefore relies on BLE radio
proximity and ESP image validation; signed/authenticated firmware is recommended
before treating OTA as secure against a nearby active attacker.

---

## Revision history

`fw` versions this document's format, and nothing else. It moves only when the
set, name, meaning or range of the reported fields changes; a firmware fix that
reports the same fields bumps `ver` and leaves `fw` alone.

### v5 — current

Emitter bank enables. The three MOSFETs of the 2026-08 board can be switched
individually (see [Emitter banks](#emitter-banks-the-other-power-control)), and
the document now says which are live.

| Change | v4 | v5 |
| --- | --- | --- |
| Enabled emitter banks | — | `banks` (uint8 bitmask, `7` = all three) |
| Control opcode `0x03` | unused | `SET_BANKS`, `0x03 + bank_mask(1)` |
| Control read-back | `state(1) + remaining_s(4 LE)` | + `bank_mask(1)`, appended |

Additive in both directions, and deliberately so. A parser that skips unknown
keys reads a v5 document as a v4 one; a client that reads five bytes of the
control read-back and stops gets exactly the value it got before. The usual
deployment-order rule still applies for the same reason it did at v4: a HiveHub
that does not understand `banks` cannot tell a switched-off bank from a dead
FET, and it is HiveHub that switches them off.

A counter running v4 or earlier has no `SET_BANKS` opcode. The write is ignored
and logged as an unknown opcode, so the feature degrades to "this counter runs
all three banks" — never to an error. HiveHub gates the write on `fw >= 5`
rather than relying on that.

### v4

Night mode. The counter can be told to stop sensing for a bounded period (see
[Night mode](#night-mode-the-control-characteristic)), and the document now says
when it has.

| Change | v3 | v4 |
| --- | --- | --- |
| Suspension countdown | — | `idle_s` (uint32, seconds remaining, `0` while counting) |
| `status` bit `0x80` | unused | `STATUS_NIGHT_IDLE` |
| Control characteristic | — | `8e8b0103-…`, READ + WRITE |

The addition is purely additive: v4 documents carry every v3 key unchanged, so a
parser that skips unknown keys reads one correctly without knowing about night
mode at all. HiveHub's `bee_counter_wire.h` does exactly that, which is why the
usual deployment-order rule is a formality here rather than a hazard — but it
still applies, because a HiveHub that does not understand `idle_s` cannot tell a
suspended counter from a broken one, and it is HiveHub that decides when to
suspend.

### v3

Three contract-level defects that could not be fixed on the counter alone,
fixed together so the fleet needs one coordinated deployment rather than three.

| Change | v2 | v3 |
| --- | --- | --- |
| `uptime_s` | `uint16_t`, clamped at 65535 (18 h 12 min) | `uint32_t`, no clamp |
| `glitches` | `uint16_t`, saturating at 65535 | `uint32_t`, saturating at 4294967295 |
| MCP health field | `gates_healthy` | `mcps_healthy` (same 0..3 value) |

The rename carries no change in meaning: the field counted MCP23017 expanders
in v2 as well. What changed is that the name no longer claims otherwise —
`gates_healthy: 3` next to `num_gates: 24` read as "21 of 24 gates dead" to
every consumer that met it, including HiveHub's own API documentation and its
mock server, both of which had it wrong.

**Deployment order matters.** HiveHub's tolerant parser must be deployed before
any counter that emits `fw: 3`. A counter in the field keeps reporting `fw: 2`
until it is updated over the air, and the OTA relay reads this very
characteristic before it can update anything — so a HiveHub that understood only
v3 would strand exactly the devices needing the update, and a HiveHub that
understood only v2 goes blind the moment a counter is updated.

### v2 — the last wired revision

Numbered an OTA-over-I2C register block that no longer exists. The number was
carried forward rather than reset to 1 when the transport became BLE/GATT, so a
HiveHub that has seen both generations never sees the format revision go
backwards.

---

## Known limitations of the current wire format

These are contract-level issues that cannot be fixed on the counter alone —
each needs HiveHub's parser to change in step, so they are deliberately left
alone until both sides can be revised together.

* **The GATT service has no authentication.** There is no pairing, no
  authorization and no firmware signature check: CRC-32 is an integrity check,
  not an authenticity one, so anyone in radio range can push a validly-framed
  image — and, since v4, write a `SET_IDLE` and stop the counter for up to an
  hour, or, since v5, a `SET_BANKS` and dark two thirds of its entrance. Both
  are strictly the lesser of the two (neither is persisted, both are re-asserted
  by HiveHub within one upload cycle, and anyone able to do either could already
  replace the firmware), but they are new ways to deny counting and they are
  named here rather than left to be discovered. This is an accepted, documented risk rather than an oversight, but
  closing it needs a design decision (Secure Boot + signed images vs. a
  BLE-layer authentication handshake vs. a per-device provisioning key) *and* a
  migration story for counters already in the field, since an unauthenticated
  device cannot be given a key over an unauthenticated channel. It belongs in
  its own piece of work.
* **`partitions_4mb_ota_no_fs.csv` reserves 64 KiB for SPIFFS** despite its
  name. Reclaiming it means resizing the OTA app slots, and a deployed device
  cannot migrate a partition table over an application-only OTA — so this is
  frozen for anything already shipped.

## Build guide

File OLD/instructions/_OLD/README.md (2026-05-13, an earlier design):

# 2019 Easy Bee Counter V.1 Build Instructions

This version of the bee counter is all through hole components. It's easy to solder and assemble. This is the 2nd version of the board (V1) completed March 2020. If you got the [Version 0](https://github.com/hydronics2/2019-easy-bee-counter/tree/b06d461f1881f2709d81f82d817dc76170a77fa7) board (Jan/Feb 2020) you just have to fix some of my previous mistakes including adding a jumper wire shown [here](https://github.com/hydronics2/2019-easy-bee-counter/blob/master/instructions/archive)

1) Install IR sensors - [QRE1113](https://www.mouser.com/ProductDetail/512-QRE1113f) or [ITR8307](https://lcsc.com/product-detail/Photo-Interrupter_Everlight-Elec-ITR8307_C63451.html)

(https://youtu.be/Xx23OmlHwkE)



2) install shift registers qty(6), SIP 22R LED resistors and 100k pulldown resistors.
- Shift registers, qty(6) [74HC165](https://www.mouser.com/ProductDetail/595-SN74HC165N)
- [22ohm resistors](https://www.mouser.com/ProductDetail/Xicon/266-22-RC?qs=sGAEpiMZZMvrmc6UYKmaNXFefT4dxyTCwtpTxTI0yoo%3D), bussed, qty(4)
SIP Packaged, bussed
- [100k ohm resistors](https://www.mouser.com/ProductDetail/IRC-TT-Electronics/L091S104LF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) bussed, qty(6)
SIP-9, 8 resistors, 9 pins



3) install power mosfets qty(2),
- N-Channel Mosfet [FQP30N06](https://www.mouser.com/ProductDetail/512-FQP30N06L)



4) install small capacitors



5) place/solder 3.3V power regulator

- [3.3V Regulator](https://www.mouser.com/ProductDetail/Microchip-Technology/MCP1826S-3302E-AB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), (input, ground, output - IGO, pinout), qty(1)



6) install large Capacitor

- [560uF, 6.3V Capacitor](https://www.mouser.com/ProductDetail/661-APSC6R3L561MH08S)



7) install green screw terminals, qty(3)

- [screw terminals](https://www.mouser.com/ProductDetail/490-TB006-508-02BE) Two pin, 0.1", qty(3)



8) install headers for microprocessor



9) install qty(4) 10K Resistors (picture is wrong.. only shows 2 resistors)
- i2c pullup resistors
- pulldown resistors for power mosfets



## TEST sensors
Before you go any farther, test all your LEDs/sensors! It's much easier to test these now before going further.
Run the sample code [blink_IR_Leds](https://github.com/hydronics2/2019-easy-bee-counter/blob/master/arduino/Blink_IR_Leds/Blink_IR_Leds.ino).

The IR LEDs are invisible to the human eye but many phones and cameras allow you to see the IR LEDs. See picture. (unfortunately most iphones have IR filters so try another phone until you see IR leds). This step is very important so make sure you can see all the LEDs.

(https://youtu.be/hH9fQr7Om6E)

LEDs look good? If no LEDs are blinking? Check to make sure you have 3.3V on the 3.3V pin header. If one or two LEDs are out, reflow your pins and/or replace the LEDs until you get 100% LEDs blinking together.

LEDs good, great, next test the shift registers with the sample code [test_shift_registers](https://github.com/hydronics2/2019-easy-bee-counter/blob/master/arduino/test_shift_registers/test_shift_registers.ino). Use a white piece of paper to trigger the sensors. If some sensors are not working, check your pins, heat up and reflow solder on pins as needed.



10) Finish assembly once all sensors are tested. Install the headers that connect the top PCB to the bottom PCB.





11) Ok, once everything is tested out, you can solder these jumpers.... Soldering the 24 jumpers increases the throw range of the IR sensors by increasing the forward voltage and current in the LED. This is fine to do if we keep the LEDs ON time to less than 100us.

Two scripts provided, both [test_shift_registers](https://github.com/hydronics2/2019-easy-bee-counter/blob/master/arduino/test_shift_registers/test_shift_registers.ino) and [bee_counting](https://github.com/hydronics2/2019-easy-bee-counter/blob/master/arduino/bee_counting/bee_counting.ino) satisfy this requirement by only turning the LEDs ON for 75us.  This is shown on line 68 (shift register) and line 158 (bee_counting).

Solder all 24 of the jumpers.


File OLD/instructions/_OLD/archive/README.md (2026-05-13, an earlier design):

# 2019 Easy Bee Counter V.0 Build Instructions

I made a few mistakes on the first version (v0). The 74hc165 is not a true SPI device. It doesn't have a tri-state buffer on the MISO.

https://electronics.stackexchange.com/questions/121249/how-to-put-a-74hc165-on-an-spi-bus

The following fix, allows you to shift in all the data at once (all shift registers)... all shift registers are therefore always enabled. This fix wil work with all the stand alone feather micro-controllers... ESP32, ESP8266, SAMD21 M0 and M4... but doesn't work with the [LoRa module](https://cdn-learn.adafruit.com/assets/assets/000/031/658/original/feather_schem.png?1460518302) as it ALSO uses the SPI buss. In order to work with the LORa module you need to swap out the 74hc165 shift registers with true SPI based shift registers... like the 74HC589 referenced in the above [stack exchange](https://electronics.stackexchange.com/a/128220) answer.

To fix the old board... we want to read all 6 shift registers so just cut one of the MISO signal lines and add a jumper.

video cutting signal https://photos.app.goo.gl/VkyV412uJGBNS7sx8

video adding jumper https://photos.app.goo.gl/QXMhvH7FzpDfXWLs7

Top view showing cut jumper
foo

Top view showing jumper(blue)
foo

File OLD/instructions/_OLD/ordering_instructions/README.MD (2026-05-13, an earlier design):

## Ordering from JLCPCB

There are a lot of different PCB manufacturers to choose from. These instructions show JLCPCB. You need a manufacturer that can make black PCBs if you want to use the PCBs to make a sandwich. The IR LEDs/sensors need to point to a black surface to prevent false triggers, so the bottom PCB has to be black.

1. Download the entire repo... hit the large green button that says "clone or download" [github](https://github.com/hydronics2/2019-easy-bee-counter)... navigate to the Eagle_v0.2 file. These are the PCB files. Do not use the kiCad files as there is a missing trace for the SCK pin for the itsybitsy footprint.
2. Go to [JLCPCB.com](https://jlcpcb.com/quote#/), create an account and click the ORDER NOW button.
3. Add your PCB files.


4. Select 'Black' as the PCB color.  Also for "Remove Order Number", select YES
[pic](https://github.com/hydronics2/2019-easy-bee-counter/blob/master/pics/JLCPCB_order.PNG)

The cost is about $8 for a minimum order of qty(5) PCBs plus $9-16 shipping depending on method.

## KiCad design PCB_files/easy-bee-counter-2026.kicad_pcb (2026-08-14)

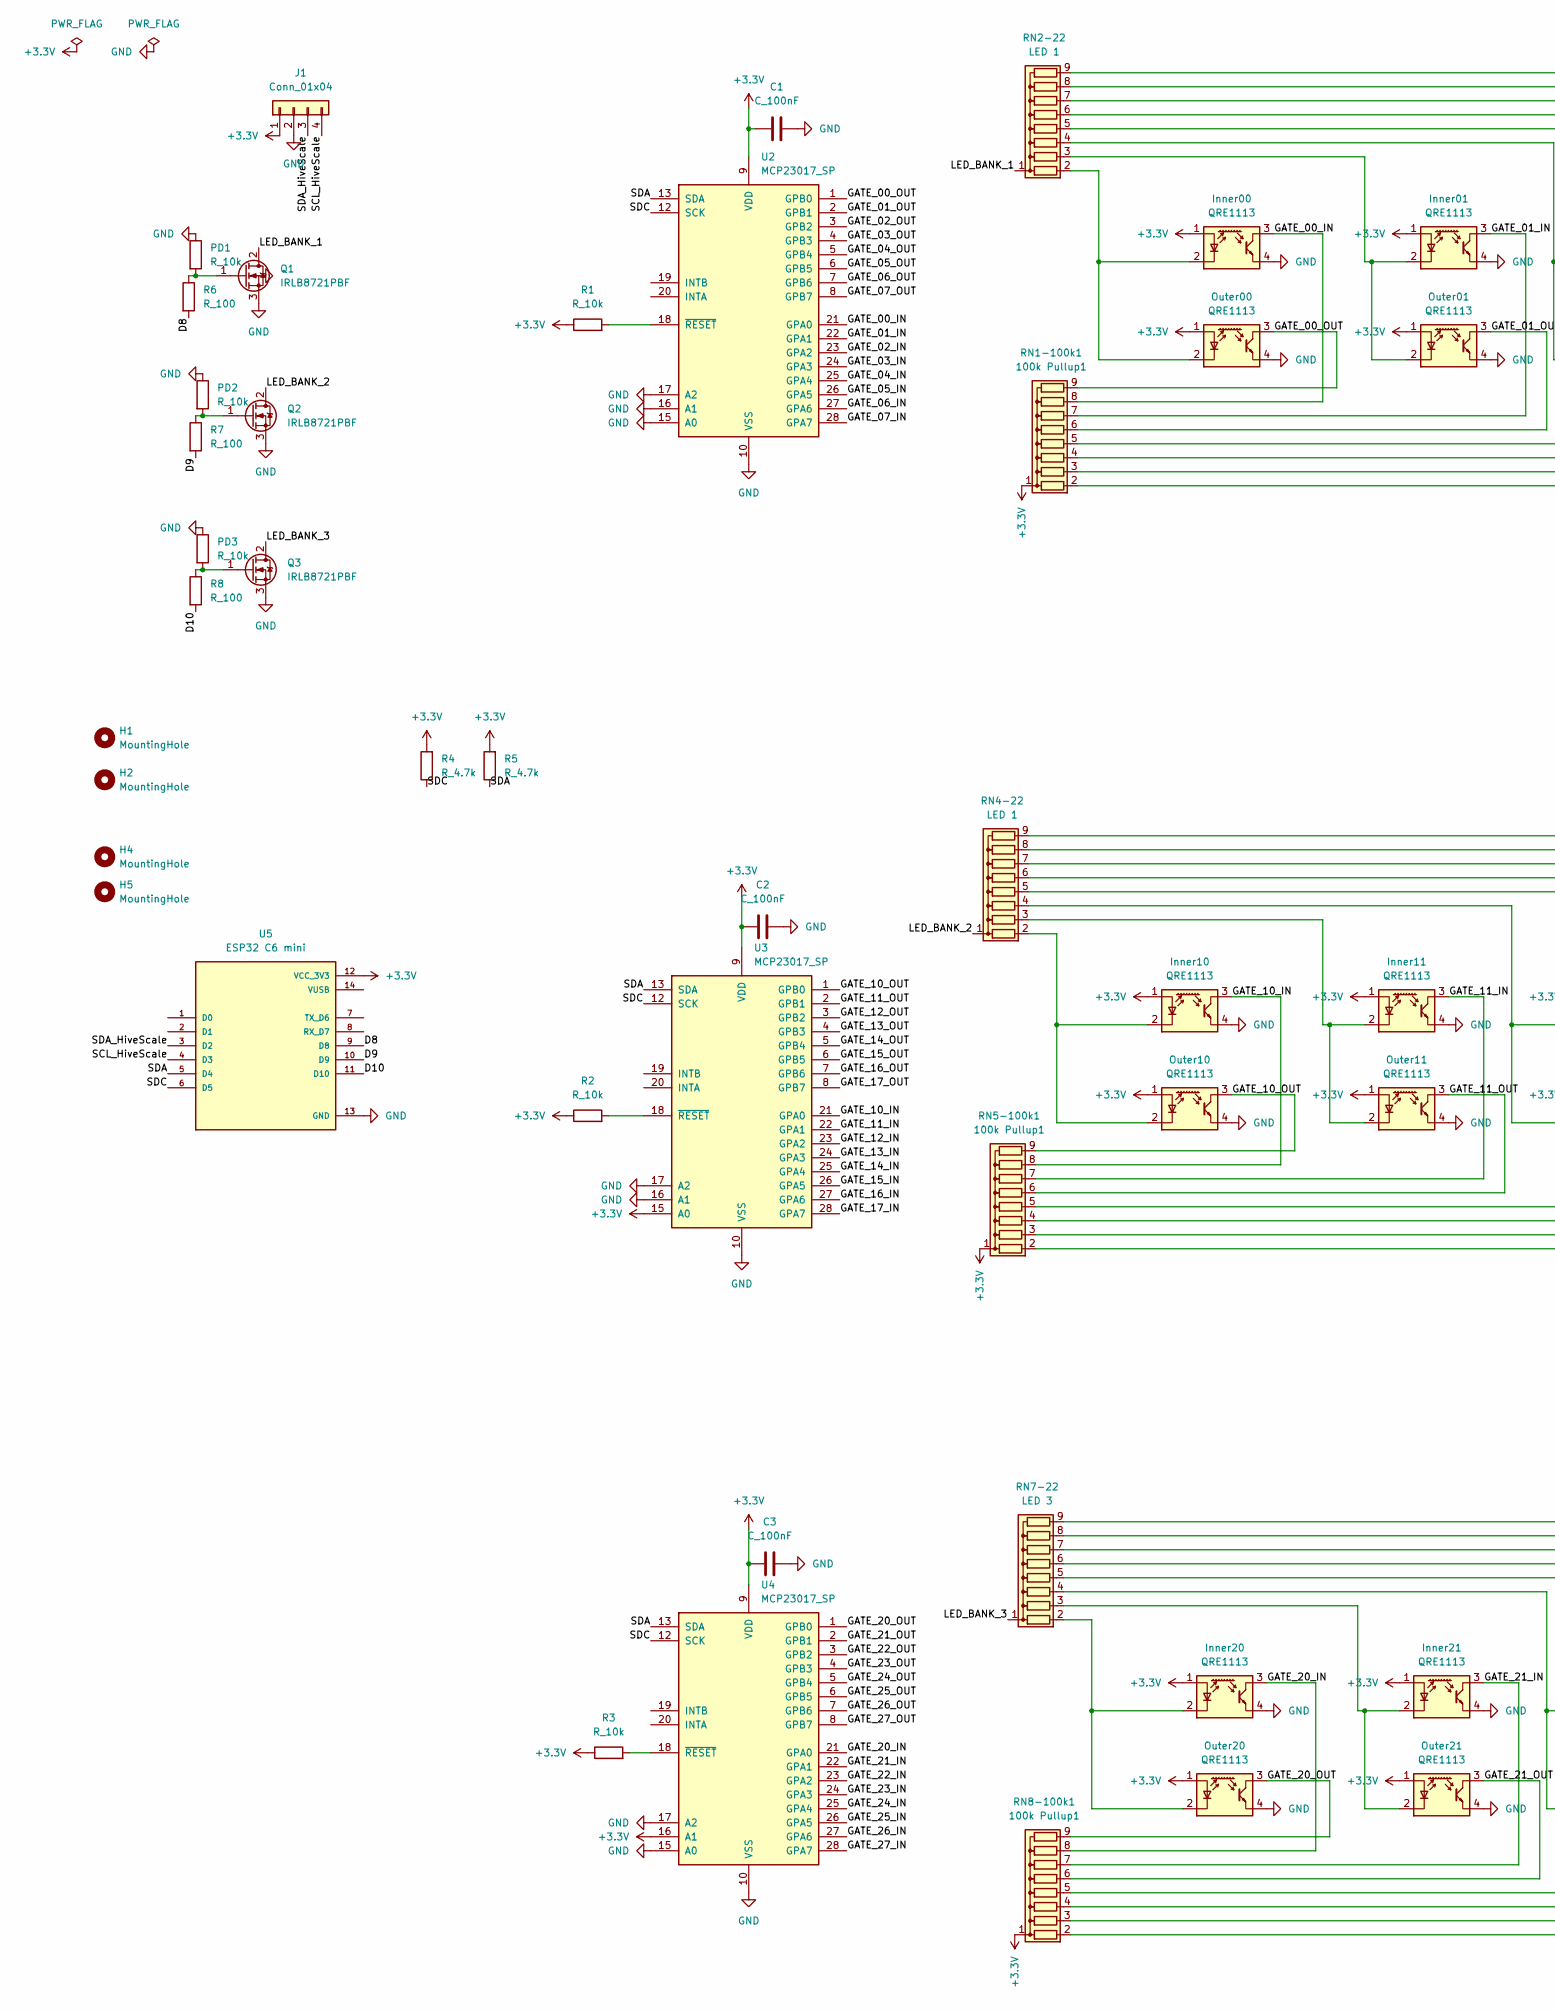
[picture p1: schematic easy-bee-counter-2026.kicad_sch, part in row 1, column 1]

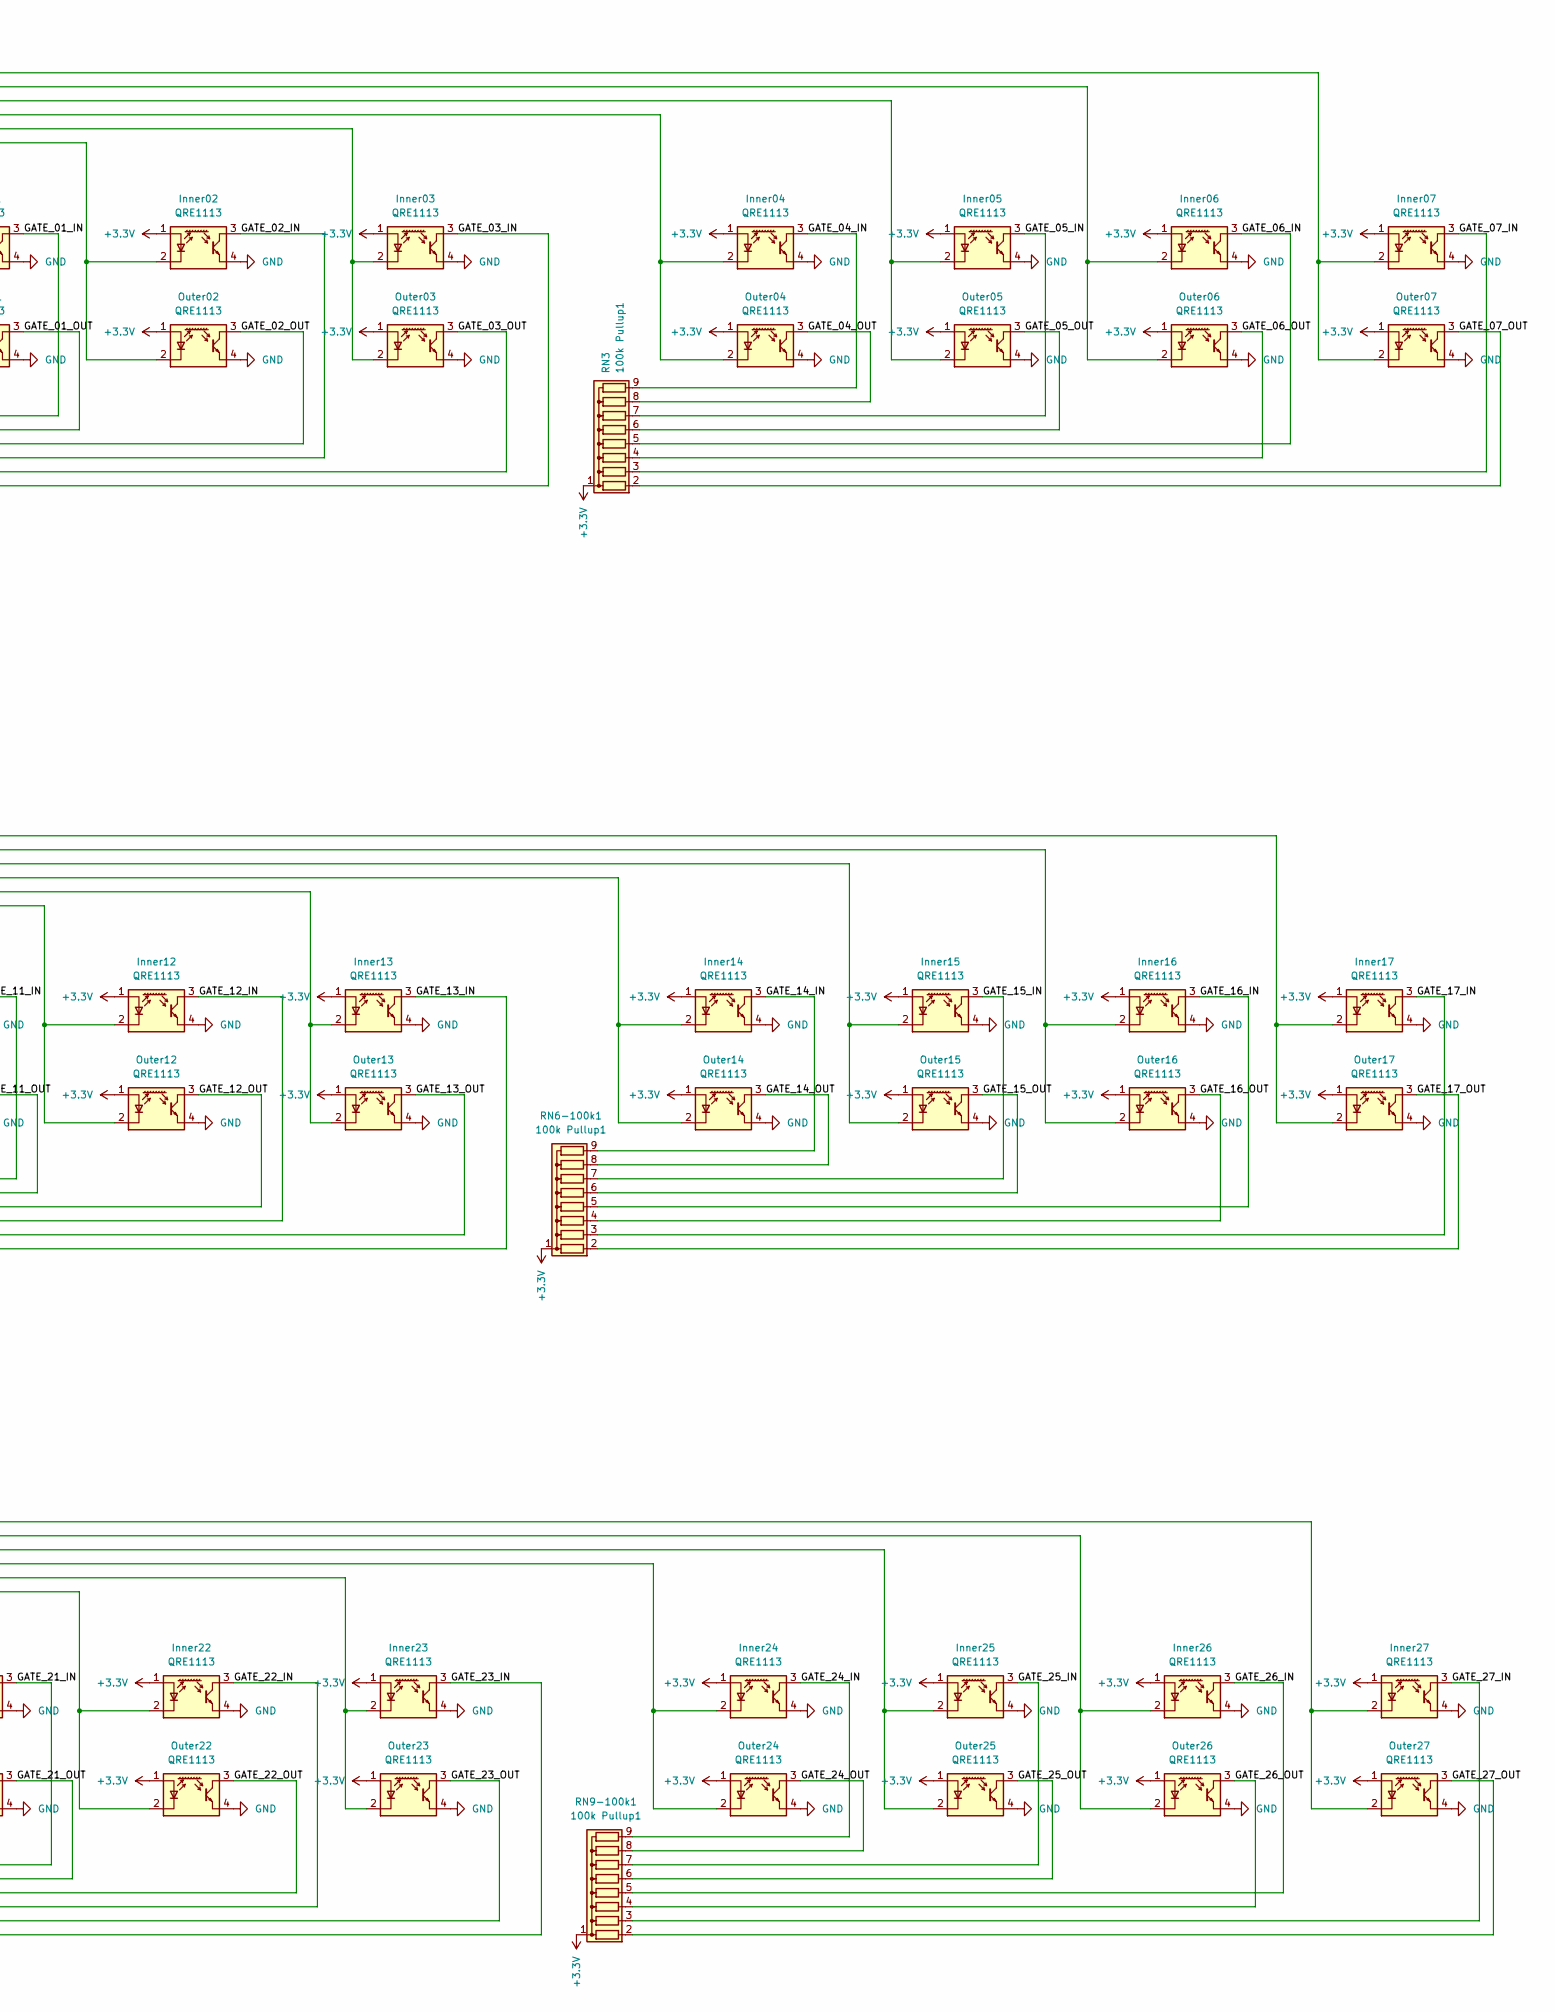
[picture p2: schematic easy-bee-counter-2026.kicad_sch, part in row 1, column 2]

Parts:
C1, C2, C3: C_100nF; C_Disc_D5.0mm_W2.5mm_P5.00mm
H1, H2, H4, H5: MountingHole; MountingHole_3.2mm_M3
Inner00, Inner01, Inner02, Inner03, Inner04, Inner05, Inner06, Inner07, Inner10, Inner11, Inner12, Inner13, Inner14, Inner15, Inner16, Inner17, Inner20, Inner21, Inner22, Inner23, Inner24, Inner25, Inner26, Inner27: QRE1113; OnSemi_CASE100AQ
J1: Conn_01x04; TerminalBlock_Xinya_XY308-2.54-4P_1x04_P2.54mm_Horizontal
Outer00, Outer01, Outer02, Outer03, Outer04, Outer05, Outer06, Outer07, Outer10, Outer11, Outer12, Outer13, Outer14, Outer15, Outer16, Outer17, Outer20, Outer21, Outer22, Outer23, Outer24, Outer25, Outer26, Outer27: QRE1113; OnSemi_CASE100AQ
PD1, PD2, PD3: R_10k; R_Axial_DIN0207_L6.3mm_D2.5mm_P7.62mm_Horizontal
Q1, Q2, Q3: IRLB8721PBF; TO-220-3_Vertical
R1, R2, R3: R_10k; R_Axial_DIN0207_L6.3mm_D2.5mm_P7.62mm_Horizontal
R4, R5: R_4.7k; R_Axial_DIN0207_L6.3mm_D2.5mm_P7.62mm_Horizontal
R6, R7, R8: R_100; R_Axial_DIN0207_L6.3mm_D2.5mm_P7.62mm_Horizontal
RN1-100k1, RN3, RN5-100k1, RN6-100k1, RN8-100k1, RN9-100k1: 100k Pullup1; R_Array_SIP9
RN2-22, RN4-22: LED 1; R_Array_SIP9
RN7-22: LED 3; R_Array_SIP9
U2, U3, U4: MCP23017_SP; DIP-28_W7.62mm
U5: ESP32 C6 mini; MODULE_113991054; PARTREV 23/05/2022

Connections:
+3.3V: C1.1, C2.1, C3.1, Inner00.1 (A), Inner01.1 (A), Inner02.1 (A), Inner03.1 (A), Inner04.1 (A), Inner05.1 (A), Inner06.1 (A), Inner07.1 (A), Inner10.1 (A), Inner11.1 (A), Inner12.1 (A), Inner13.1 (A), Inner14.1 (A), Inner15.1 (A), Inner16.1 (A), Inner17.1 (A), Inner20.1 (A), Inner21.1 (A), Inner22.1 (A), Inner23.1 (A), Inner24.1 (A), Inner25.1 (A), Inner26.1 (A), Inner27.1 (A), J1.1, Outer00.1 (A), Outer01.1 (A), Outer02.1 (A), Outer03.1 (A), Outer04.1 (A), Outer05.1 (A), Outer06.1 (A), Outer07.1 (A), Outer10.1 (A), Outer11.1 (A), Outer12.1 (A), Outer13.1 (A), Outer14.1 (A), Outer15.1 (A), Outer16.1 (A), Outer17.1 (A), Outer20.1 (A), Outer21.1 (A), Outer22.1 (A), Outer23.1 (A), Outer24.1 (A), Outer25.1 (A), Outer26.1 (A), Outer27.1 (A), R1.1, R2.1, R3.1, R4.2, R5.2, RN1-100k1.1 (common), RN3.1 (common), RN5-100k1.1 (common), RN6-100k1.1 (common), RN8-100k1.1 (common), RN9-100k1.1 (common), U2.9 (VDD), U3.9 (VDD), U3.15 (A0), U4.9 (VDD), U4.16 (A1), U5.12 (VCC_3V3)
/D8: R6.2, U5.9 (D8)
/D9: R7.2, U5.10 (D9)
/D10: R8.2, U5.11 (D10)
/GATE_00_IN: Inner00.3, RN1-100k1.8 (R7), U2.21 (GPA0)
/GATE_00_OUT: Outer00.3, RN1-100k1.9 (R8), U2.1 (GPB0)
/GATE_01_IN: Inner01.3, RN1-100k1.7 (R6), U2.22 (GPA1)
/GATE_01_OUT: Outer01.3, RN1-100k1.6 (R5), U2.2 (GPB1)
/GATE_02_IN: Inner02.3, RN1-100k1.4 (R3), U2.23 (GPA2)
/GATE_02_OUT: Outer02.3, RN1-100k1.5 (R4), U2.3 (GPB2)
/GATE_03_IN: Inner03.3, RN1-100k1.2 (R1), U2.24 (GPA3)
/GATE_03_OUT: Outer03.3, RN1-100k1.3 (R2), U2.4 (GPB3)
/GATE_04_IN: Inner04.3, RN3.9 (R8), U2.25 (GPA4)
/GATE_04_OUT: Outer04.3, RN3.8 (R7), U2.5 (GPB4)
/GATE_05_IN: Inner05.3, RN3.7 (R6), U2.26 (GPA5)
/GATE_05_OUT: Outer05.3, RN3.6 (R5), U2.6 (GPB5)
/GATE_06_IN: Inner06.3, RN3.5 (R4), U2.27 (GPA6)
/GATE_06_OUT: Outer06.3, RN3.4 (R3), U2.7 (GPB6)
/GATE_07_IN: Inner07.3, RN3.3 (R2), U2.28 (GPA7)
/GATE_07_OUT: Outer07.3, RN3.2 (R1), U2.8 (GPB7)
/GATE_10_IN: Inner10.3, RN5-100k1.8 (R7), U3.21 (GPA0)
/GATE_10_OUT: Outer10.3, RN5-100k1.9 (R8), U3.1 (GPB0)
/GATE_11_IN: Inner11.3, RN5-100k1.7 (R6), U3.22 (GPA1)
/GATE_11_OUT: Outer11.3, RN5-100k1.6 (R5), U3.2 (GPB1)
/GATE_12_IN: Inner12.3, RN5-100k1.4 (R3), U3.23 (GPA2)
/GATE_12_OUT: Outer12.3, RN5-100k1.5 (R4), U3.3 (GPB2)
/GATE_13_IN: Inner13.3, RN5-100k1.2 (R1), U3.24 (GPA3)
/GATE_13_OUT: Outer13.3, RN5-100k1.3 (R2), U3.4 (GPB3)
/GATE_14_IN: Inner14.3, RN6-100k1.9 (R8), U3.25 (GPA4)
/GATE_14_OUT: Outer14.3, RN6-100k1.8 (R7), U3.5 (GPB4)
/GATE_15_IN: Inner15.3, RN6-100k1.7 (R6), U3.26 (GPA5)
/GATE_15_OUT: Outer15.3, RN6-100k1.6 (R5), U3.6 (GPB5)
/GATE_16_IN: Inner16.3, RN6-100k1.5 (R4), U3.27 (GPA6)
/GATE_16_OUT: Outer16.3, RN6-100k1.4 (R3), U3.7 (GPB6)
/GATE_17_IN: Inner17.3, RN6-100k1.3 (R2), U3.28 (GPA7)
/GATE_17_OUT: Outer17.3, RN6-100k1.2 (R1), U3.8 (GPB7)
/GATE_20_IN: Inner20.3, RN8-100k1.8 (R7), U4.21 (GPA0)
/GATE_20_OUT: Outer20.3, RN8-100k1.9 (R8), U4.1 (GPB0)
/GATE_21_IN: Inner21.3, RN8-100k1.7 (R6), U4.22 (GPA1)
/GATE_21_OUT: Outer21.3, RN8-100k1.6 (R5), U4.2 (GPB1)
/GATE_22_IN: Inner22.3, RN8-100k1.4 (R3), U4.23 (GPA2)
/GATE_22_OUT: Outer22.3, RN8-100k1.5 (R4), U4.3 (GPB2)
/GATE_23_IN: Inner23.3, RN8-100k1.2 (R1), U4.24 (GPA3)
/GATE_23_OUT: Outer23.3, RN8-100k1.3 (R2), U4.4 (GPB3)
/GATE_24_IN: Inner24.3, RN9-100k1.9 (R8), U4.25 (GPA4)
/GATE_24_OUT: Outer24.3, RN9-100k1.8 (R7), U4.5 (GPB4)
/GATE_25_IN: Inner25.3, RN9-100k1.7 (R6), U4.26 (GPA5)
/GATE_25_OUT: Outer25.3, RN9-100k1.6 (R5), U4.6 (GPB5)
/GATE_26_IN: Inner26.3, RN9-100k1.5 (R4), U4.27 (GPA6)
/GATE_26_OUT: Outer26.3, RN9-100k1.4 (R3), U4.7 (GPB6)
/GATE_27_IN: Inner27.3, RN9-100k1.3 (R2), U4.28 (GPA7)
/GATE_27_OUT: Outer27.3, RN9-100k1.2 (R1), U4.8 (GPB7)
/LED_BANK_1: Q1.2 (D), RN2-22.1 (common)
/LED_BANK_2: Q2.2 (D), RN4-22.1 (common)
/LED_BANK_3: Q3.2 (D), RN7-22.1 (common)
/SCL_HiveScale: J1.4, U5.4 (D3)
/SDA: R5.1, U2.13 (SDA), U3.13 (SDA), U4.13 (SDA), U5.5 (D4)
/SDA_HiveScale: J1.3, U5.3 (D2)
/SDC: R4.1, U2.12 (SCK), U3.12 (SCK), U4.12 (SCK), U5.6 (D5)
GND: C1.2, C2.2, C3.2, Inner00.4, Inner01.4, Inner02.4, Inner03.4, Inner04.4, Inner05.4, Inner06.4, Inner07.4, Inner10.4, Inner11.4, Inner12.4, Inner13.4, Inner14.4, Inner15.4, Inner16.4, Inner17.4, Inner20.4, Inner21.4, Inner22.4, Inner23.4, Inner24.4, Inner25.4, Inner26.4, Inner27.4, J1.2, Outer00.4, Outer01.4, Outer02.4, Outer03.4, Outer04.4, Outer05.4, Outer06.4, Outer07.4, Outer10.4, Outer11.4, Outer12.4, Outer13.4, Outer14.4, Outer15.4, Outer16.4, Outer17.4, Outer20.4, Outer21.4, Outer22.4, Outer23.4, Outer24.4, Outer25.4, Outer26.4, Outer27.4, PD1.1, PD2.1, PD3.1, Q1.3 (S), Q2.3 (S), Q3.3 (S), U2.10 (VSS), U2.15 (A0), U2.16 (A1), U2.17 (A2), U3.10 (VSS), U3.16 (A1), U3.17 (A2), U4.10 (VSS), U4.15 (A0), U4.17 (A2), U5.13 (GND)
unnamed: Inner00.2 (K), Outer00.2 (K), RN2-22.2 (R1)
unnamed: Inner01.2 (K), Outer01.2 (K), RN2-22.3 (R2)
unnamed: Inner02.2 (K), Outer02.2 (K), RN2-22.4 (R3)
unnamed: Inner03.2 (K), Outer03.2 (K), RN2-22.5 (R4)
unnamed: Inner04.2 (K), Outer04.2 (K), RN2-22.6 (R5)
unnamed: Inner05.2 (K), Outer05.2 (K), RN2-22.7 (R6)
unnamed: Inner06.2 (K), Outer06.2 (K), RN2-22.8 (R7)
unnamed: Inner07.2 (K), Outer07.2 (K), RN2-22.9 (R8)
unnamed: Inner10.2 (K), Outer10.2 (K), RN4-22.2 (R1)
unnamed: Inner11.2 (K), Outer11.2 (K), RN4-22.3 (R2)
unnamed: Inner12.2 (K), Outer12.2 (K), RN4-22.4 (R3)
unnamed: Inner13.2 (K), Outer13.2 (K), RN4-22.5 (R4)
unnamed: Inner14.2 (K), Outer14.2 (K), RN4-22.6 (R5)
unnamed: Inner15.2 (K), Outer15.2 (K), RN4-22.7 (R6)
unnamed: Inner16.2 (K), Outer16.2 (K), RN4-22.8 (R7)
unnamed: Inner17.2 (K), Outer17.2 (K), RN4-22.9 (R8)
unnamed: Inner20.2 (K), Outer20.2 (K), RN7-22.2 (R1)
unnamed: Inner21.2 (K), Outer21.2 (K), RN7-22.3 (R2)
unnamed: Inner22.2 (K), Outer22.2 (K), RN7-22.4 (R3)
unnamed: Inner23.2 (K), Outer23.2 (K), RN7-22.5 (R4)
unnamed: Inner24.2 (K), Outer24.2 (K), RN7-22.6 (R5)
unnamed: Inner25.2 (K), Outer25.2 (K), RN7-22.7 (R6)
unnamed: Inner26.2 (K), Outer26.2 (K), RN7-22.8 (R7)
unnamed: Inner27.2 (K), Outer27.2 (K), RN7-22.9 (R8)
unnamed: PD1.2, Q1.1 (G), R6.1
unnamed: PD2.2, Q2.1 (G), R7.1
unnamed: PD3.2, Q3.1 (G), R8.1
unnamed: R1.2, U2.18 (~RESET)
unnamed: R2.2, U3.18 (~RESET)
unnamed: R3.2, U4.18 (~RESET)

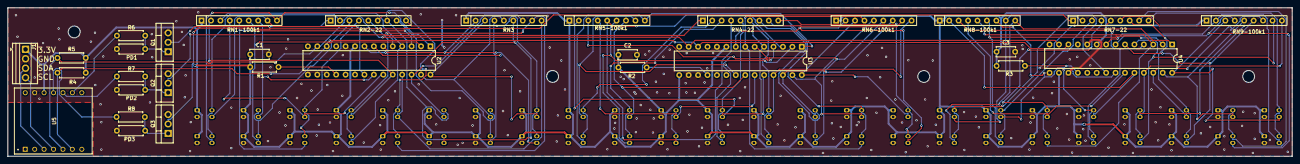
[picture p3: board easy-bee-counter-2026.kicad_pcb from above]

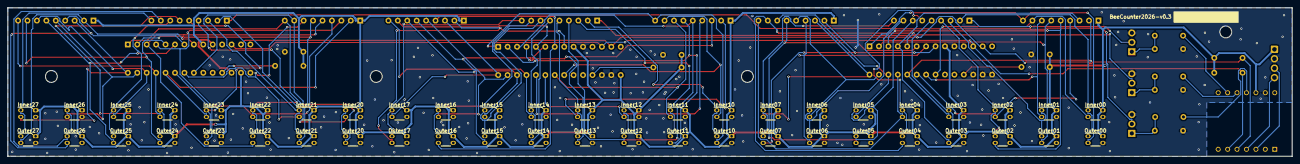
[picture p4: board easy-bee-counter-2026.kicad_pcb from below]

Board: 2 copper layers, 346.0 x 40.0 mm, 83 parts (48 on the bottom side), 90 nets.

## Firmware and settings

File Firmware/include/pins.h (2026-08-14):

// ============================================================================
// pins.h — Easy Bee Counter 2026 hardware map
// ============================================================================
// All physical pin numbers and I2C addresses were derived from the KiCad
// schematic (easy-bee-counter-2026.kicad_sch) and the netlist export
// (easy-bee-counter-2026.net). Update this file if the PCB is revised.
// ============================================================================
//
// ESP32-C6 mini silk-label -> GPIO mapping
// ----------------------------------------
// U5 is a Seeed XIAO ESP32C6 (schematic symbol "ESP32 C6 mini", Seeed part
// 113991054), NOT a bare ESP32-C6-MINI-1 module. That distinction is the whole
// reason this table exists: on the XIAO form factor the silk labels D0..D10 do
// *not* equal the GPIO numbers. The authority is the Arduino core variant
// header variants/XIAO_ESP32C6/pins_arduino.h:
//
//   silk   GPIO   net on this PCB
//   ----   ----   ---------------------------------------------------------
//   D0  -> GPIO0
//   D1  -> GPIO1
//   D2  -> GPIO2   SDA_HiveScale (unused: the wired link was removed)
//   D3  -> GPIO21  SCL_HiveScale (unused: the wired link was removed)
//   D4  -> GPIO22  /SDA   (I2C data, MCP23017 master bus)
//   D5  -> GPIO23  /SDC   (I2C clock, schematic spells it "SDC")
//   D6  -> GPIO16  TX (UART0)                    [unused on this board]
//   D7  -> GPIO17  RX (UART0)                    [unused on this board]
//   D8  -> GPIO19  /GPIO4 net -> Q1 gate (LED_BANK_1 enable, gates 00..07)
//   D9  -> GPIO20  /GPIO5 net -> Q2 gate (LED_BANK_2 enable, gates 10..17)
//   D10 -> GPIO18  /GPIO6 net -> Q3 gate (LED_BANK_3 enable, gates 20..27)
//
// Two traps live in that table, and this firmware fell into both:
//
//   1. The schematic net labels "/GPIO4", "/GPIO5" and "/GPIO6" do NOT mean
//      physical GPIO4/5/6 — they are just net names. Physically they land on U5
//      pins 9, 10 and 11, silk-labelled D8, D9 and D10, i.e. GPIO19, GPIO20 and
//      GPIO18.
//   2. GPIO3..GPIO15 are simply not on the XIAO header. Assigning a bus to one
//      of them compiles and boots happily, drives nothing, and every device on
//      the real bus reports NOT FOUND. GPIO3 in particular is tied to the
//      module's RF antenna switch, so using it also disturbs the radio.
//
// Always write the GPIO number here, never the silk number. The PlatformIO
// board is seeed_xiao_esp32c6; its XIAO_ESP32C6 variant does define the
// D0..D10 aliases above, but it does not enable the core's pin remapping
// (BOARD_HAS_PIN_REMAP), so an Arduino pin number is still a raw GPIO number
// and the constants below are read literally.
//
// I2C bus layout
// --------------
//   Bus 0 (Wire) — MASTER, GPIO22/D4 (SDA) / GPIO23/D5 (SCL). Talks to the 3x
//                  MCP23017 port expanders. On-board pull-ups R4/R5 (4.7k each).
//
// The PCB also routes a second bus to J1 on D2/D3 (GPIO2/GPIO21), which earlier
// firmware ran as a permanent I2C slave for a HiveScale. That link is gone: the
// counter reports over BLE only. The pads and traces are harmless — the firmware
// simply never brings up the second controller, so the pins stay inputs.
//
// MCP23017 addresses (set by A0/A1/A2 strap pins, base 0x20):
//   U2 -> A0=0 A1=0 A2=0 -> 0x20  (gates 00..07)
//   U3 -> A0=1 A1=0 A2=0 -> 0x21  (gates 10..17)
//   U4 -> A0=0 A1=1 A2=0 -> 0x22  (gates 20..27)
//
// MCP23017 GPIO assignment per chip:
//   GPA0..GPA7 -> Inner sensor of gate N0..N7 (data line of QRE1113 pin 3)
//   GPB0..GPB7 -> Outer sensor of gate N0..N7 (data line of QRE1113 pin 3)
//
// In the Adafruit_MCP23X17 library, digitalRead(0..7) -> port A,
// digitalRead(8..15) -> port B, so:
//   inner sensor of gate K -> mcp.digitalRead(K)        // 0..7
//   outer sensor of gate K -> mcp.digitalRead(K + 8)    // 8..15
//
// QRE1113 wiring on this board:
//   - Each phototransistor collector goes to its MCP pin, with a 100k
//     pull-up to +3.3V (RN1/RN3/RN5/RN6/RN8/RN9).
//   - IR LEDs on a gate are tied to the LED_BANK_1, LED_BANK_2 or LED_BANK_3
//     rail, with ballast resistors in series and Q1/Q2/Q3 (IRLB8721 N-FETs) on
//     the low side. Driving the FET gate HIGH turns the IR LEDs ON, which
//     causes reflected light to drop the phototransistor collector voltage.
//   - Since the 2026-08 hardware revision there is one FET per MCP23017, so a
//     bank maps 1:1 onto a chip: U2 -> bank 1, U3 -> bank 2, U4 -> bank 3.
//     (The previous 2-FET build split U3's gates across banks 1 and 2.)
//   - Therefore the *logical* convention used in this firmware is:
//        sensor reads LOW  -> bee body in the beam (beam reflected/blocked)
//        sensor reads HIGH -> beam clear OR IR LEDs off
//
// Gate numbering
// --------------
// The PCB has 24 active gates physically. The naming has gaps (08, 09, 18, 19,
// 28, 29 are skipped) to keep the per-chip pin -> gate map clean. We expose
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

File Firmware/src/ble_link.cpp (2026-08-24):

// HiveHub-compatible BLE/GATT transport for HiveTraffic.
#include "ble_link.h"

#include <Arduino.h>
#include <NimBLEDevice.h>
#include <Update.h>
#include <stdio.h>

#include "counter_protocol.h"
#include "device_name.h"
#include "measurement_json.h"
#include "version.h"

namespace ble {
namespace {

// The advertised local name, "HiveTraffic-AB:12", built once in begin() from
// this counter's own BLE address so several in range are distinguishable in a
// scan list (include/device_name.h). File scope rather than a local in begin()
// because the log line below reads it too, and because it is the one place the
// name exists — nothing should reconstruct it.
char deviceName[devicename::CAPACITY];

constexpr char SVC_BEECOUNTER[] = "8e8b0101-7a1c-4b9e-9a2f-1d6e0b9c1a01";
constexpr char CHR_MEASUREMENT[] = "8e8b0102-7a1c-4b9e-9a2f-1d6e0b9c1a01";
// Night mode: HiveHub writes a suspension DURATION here, and reads back the
// current state. Deliberately a separate characteristic from the OTA control
// one — an image transfer and "stop sensing for a while" have nothing in
// common but a direction, and sharing an opcode space between them would mean
// a malformed OTA frame could suspend counting.
constexpr char CHR_CONTROL[] = "8e8b0103-7a1c-4b9e-9a2f-1d6e0b9c1a01";
constexpr char CHR_OTA_CTRL[] = "8e8b0110-7a1c-4b9e-9a2f-1d6e0b9c1a01";
constexpr char CHR_OTA_DATA[] = "8e8b0111-7a1c-4b9e-9a2f-1d6e0b9c1a01";
constexpr char CHR_OTA_STATUS[] = "8e8b0113-7a1c-4b9e-9a2f-1d6e0b9c1a01";
constexpr uint16_t ADV_INTERVAL_UNITS = 1600;  // 1600 * 0.625 ms = 1 second
constexpr uint8_t OTA_OP_BEGIN = 0x01;
constexpr uint8_t OTA_OP_END = 0x03;
constexpr uint8_t OTA_OP_ABORT = 0x04;
constexpr uint32_t OTA_REBOOT_DELAY_MS = 1500;
// How often, at most, a DATA write refreshes the OTA status characteristic and
// notifies subscribers.
//
// Time-based rather than byte-based (the alternative was every 4-16 KiB) because
// it bounds the notification rate no matter how fast the transfer runs: a
// byte-based threshold ties the rate to throughput, so a 517-byte-MTU link with
// a short connection interval turns a multi-megabyte image into a notify storm
// competing with the DATA writes it is reporting on, while the same threshold on
// a slow link goes nearly silent. 250 ms is at most four notifications per
// second — a smooth progress bar, and negligible next to the data traffic —
// regardless of MTU, connection interval or image size.
constexpr uint32_t OTA_PROGRESS_NOTIFY_INTERVAL_MS = 250;

using namespace beecounter_proto;

NimBLECharacteristic* otaStatus = nullptr;
volatile uint8_t otaState = OTA_STATE_IDLE;
volatile uint8_t otaError = OTA_ERR_NONE;
volatile uint32_t otaReceived = 0;
uint32_t otaSize = 0;
uint32_t otaExpectedCrc = 0;
uint32_t otaRunningCrc = 0xFFFFFFFFUL;
uint32_t otaRebootAt = 0;
uint32_t otaLastNotifyMs = 0;

static uint32_t crc32Update(uint32_t crc, const uint8_t* data, size_t length) {
    while (length--) {
        crc ^= *data++;
        for (uint8_t bit = 0; bit < 8; ++bit) {
            const uint32_t mask = static_cast<uint32_t>(
                -static_cast<int32_t>(crc & 1U));
            crc = (crc >> 1) ^ (0xEDB88320UL & mask);
        }
    }
    return crc;
}

// Build the current six-byte, little-endian status (the same layout HiveInside
// uses). Snapshotting otaReceived once matters: the four length bytes must
// describe one instant, not four.
static void buildOtaStatusValue(uint8_t (&value)[6]) {
    const uint32_t received = otaReceived;
    value[0] = otaState;
    value[1] = static_cast<uint8_t>(received);
    value[2] = static_cast<uint8_t>(received >> 8);
    value[3] = static_cast<uint8_t>(received >> 16);
    value[4] = static_cast<uint8_t>(received >> 24);
    value[5] = otaError;
}

static void publishOtaStatus() {
    if (!otaStatus) return;
    uint8_t value[6];
    buildOtaStatusValue(value);
    otaStatus->setValue(value, sizeof(value));
    otaStatus->notify();
    otaLastNotifyMs = millis();
}

static void failOta(uint8_t state) {
    if (otaState == OTA_STATE_RECEIVING) Update.abort();
    otaRebootAt = 0;
    otaState = state;
    otaError = state;
    publishOtaStatus();
}

static void refreshMeasurement(NimBLECharacteristic* characteristic) {
    Telemetry t{};
    getTelemetry(t);
    // The document itself is built by the pure serializer in
    // include/measurement_json.h, which is what test/test_measurement_json/
    // exercises on a host compiler — including the saturated worst case that
    // decides the buffer size below.
    char json[MEASUREMENT_JSON_CAPACITY];
    const int length = buildMeasurementJson(json, sizeof(json), t,
                                            HIVETRAFFIC_FW_VERSION);
    if (length <= 0) {
        Serial.println(F("[BLE] measurement serialization failed"));
        return;
    }
    characteristic->setValue(reinterpret_cast<const uint8_t*>(json), length);
}

class MeasurementCallbacks : public NimBLECharacteristicCallbacks {
    void onRead(NimBLECharacteristic* characteristic, NimBLEConnInfo&) override {
        // Build the snapshot on demand: no periodic JSON allocation or stale read.
        refreshMeasurement(characteristic);
    }
};
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

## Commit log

2026-05-13 Project Restructure
    [easy_bee_counter.brd, easy_bee_counter.sch, easy_bee_feather_route.kicad_pcb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]
2026-05-27 Added first pcb-file-version
    [easy-bee-counter-2026.kicad_pcb, easy-bee-counter-2026.kicad_sch]
2026-05-27 Initial release of BeeCounter firmware with i2c
2026-05-28 fixed 2nd i2c interface
    [main.cpp, pins.h]
2026-05-30 Added dual i2c and ota-firmware update
2026-06-12 added pulse led to firmware
2026-06-15 Add USB serial IR-sensor debug console for bench testing
    Adds an interactive, USB-only debug console gated behind a new -DIR_DEBUG
    build flag (esp32-c6-devkitc-1-irdebug env). It streams the raw inner/outer
    beam state of all 24 gates over USB CDC with no HiveScale/I2C master attached,
    and lets you force the IR LEDs on/off/auto from the serial monitor. The flag
    keeps all of this out of the production firmware.
2026-06-15 Add I2C bus scanner ('i') to IR debug console
    Probes every 7-bit address on the master bus and reports what ACKs, to
    distinguish a wiring/pin fault from an MCP23017 address-strap fault during
    bench bring-up.
2026-06-16 revised pcb design
    [easy-bee-counter-2026-B_Cu.gbr, easy-bee-counter-2026-B_Mask.gbr, easy-bee-counter-2026-B_Paste.gbr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]
2026-06-19 Add optional BLE/GATT wireless mode for the bee counter
    Mirror HiveInside's wireless transfer: a compile-time alternative
    (-DBEECOUNTER_BLE) that swaps the wired I2C slave for a connectable
    NimBLE GATT server. Because the counter's power is dominated by pulsing
    the 48 IR emitters, the radio stays advertising-connectable continuously
    with no deep-sleep / wake-sync machinery.
    - New ble_link.{h,cpp}: custom BeeCounter GATT service with a single
    compact-JSON measurement characteristic (aggregate IN/OUT totals +
    latched interval + status/health, no per-gate debug arrays, well under
    the 512-byte ATT cap), a control characteristic reusing the REG_CTRL
    CMD_* opcodes, and a firmware-over-BLE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
    [partitions_4mb_ota_no_fs.csv]
2026-08-02 Add connectable BLE OTA target
    [partitions_4mb_ota_no_fs.csv]
2026-08-02 BLE: split advertising PDUs and report the image version
    Two fixes to the connectable BLE transport, both needed before HiveHub can
    relay firmware to a counter.
    Advertising overflowed the 31-byte legacy PDU. begin() set a complete local
    name, a 128-bit service UUID and (implicitly) flags on the same advertisement:
    3 + 18 + 12 = 33 bytes. NimBLE 2.x defaults scan response off and does not
    relocate an overflowing name by itself, so one of the three was dropped —
    possibly advertising itself, which would make the counter invisible to the
    measurement read as well as to the OTA relay, since that locates the device by
    scan before connecting. The name now goes in the scan response, leaving 21
    byt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
    [ble_link.cpp]
2026-08-02 Remove the wired I2C counter link entirely
    The counter still shipped its original transport as the default build: the
    C6's second I2C controller running a permanent slave at 0x30, serving a
    register map to a HiveScale polling over J1. Nothing consumes that anymore —
    HiveHub reads counters over BLE and deleted its wired client — so it was a
    second, untested protocol kept alive by nobody.
    Deleted from main.cpp: the Wire1 slave and its onReceive/onRequest callbacks,
    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
    [partitions_4mb_ota_no_fs.csv]
2026-08-03 BLE: fix setCallbacks against NimBLE 2.5.x
    NimBLE-Arduino 2.5.x dropped the deleteCallbacks argument from
    NimBLECharacteristic::setCallbacks(), so the three characteristic
    registrations no longer compiled. The library never owned those pointers
    in the first place, so hand them stateless file-scope singletons instead
    of heap allocations that were never freed. The server keeps its
    two-argument form but now passes false, since a static must not be
    deleted.
    Also drop service->start(): it is a deprecated no-op in 2.5.x (it just
    returns true), and the GATT server is started by advertising->start().
    Claude-Session: https://claude.ai/code/sessi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
    [ble_link.cpp]
2026-08-13 Fix the I2C and IR-bank pins for the XIAO ESP32C6 silk map
    The three MCP23017s reported NOT FOUND at 0x20/0x21/0x22 on assembled
    hardware because the master bus was not on the pins the PCB routes it to.
    U5 is a Seeed XIAO ESP32C6 (schematic symbol "ESP32 C6 mini", Seeed part
    113991054), not the bare ESP32-C6-MINI-1 module the docs claimed. On the
    XIAO form factor the silk labels D0..D10 are not GPIO numbers: D4 is
    GPIO22, D5 is GPIO23, D8 is GPIO19, D9 is GPIO20, and GPIO3..GPIO15 are
    not brought out to the header at all.
    pins.h had drifted to I2C_SDA=2 / I2C_SCL=3, so Wire drove GPIO2 — the
    retired HiveScale SDA pad on J1 — and GPIO3, which is bonded to the
    module's RF antenna switch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
    [pins.h]
2026-08-14 Name build artifacts so HiveHub recognizes the image
    HiveHub's firmware upload form already reads the target, board and version
    out of a build artifact's filename, and both its docs and the form's own
    Board hint tell the operator that "HiveTraffic's build already names its
    artifact hivetraffic_esp32-c6_<version>.bin — upload that file as-is".
    It did not. This project had no rename step, so `pio run` produced a plain
    firmware.bin. Uploading that leaves Target on the default main unit and the
    Version field empty: the release is either published against the wrong
    target or has to be renamed by hand before every upload, and a hand-typed
    version is exactly the field the OTA relay gate compares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
2026-08-14 firmware: add third IR emitter bank (one MOSFET per MCP23017)
    The hardware revision replaces the 2-MOSFET emitter split with three
    IRLB8721 FETs, one per MCP23017, driven from the XIAO ESP32C6's D8/D9/D10
    (GPIO19/GPIO20/GPIO18, schematic nets /GPIO4, /GPIO5, /GPIO6):
    LED_BANK_1 -> Q1 -> D8/GPIO19 -> gates 00..07 (U2 @ 0x20)
    LED_BANK_2 -> Q2 -> D9/GPIO20 -> gates 10..17 (U3 @ 0x21)
    LED_BANK_3 -> Q3 -> D10/GPIO18 -> gates 20..27 (U4 @ 0x22)
    Banks now line up 1:1 with the expanders; previously U3's gates straddled
    banks 1 and 2 (00..13 / 14..27).
    - pins.h: add IR_LED_BANK_3_EN, NUM_LED_BANKS and the IR_LED_BANK_EN[]
    lookup so callers can iterate banks instead of naming each pin; reta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
    [main.cpp, pins.h]
2026-08-14 firmware: target seeed_xiao_esp32c6, drop the IR-debug environment
    U5 is a Seeed XIAO ESP32C6, so build against the board profile that matches
    the hardware instead of the generic devkit one:
    * seeed_xiao_esp32c6 declares the module's real 4 MB flash (the devkit
    profile declared 8 MB, which is what ends up in the image header) and
    pulls in the XIAO_ESP32C6 variant.
    * That variant defines the D0..D10 aliases but does not enable Arduino pin
    remapping (no BOARD_HAS_PIN_REMAP), so the raw GPIO numbers in pins.h are
    unchanged and still correct. Its SDA/SCL defaults (22/23) also agree with
    the PCB.
    * partitions_4mb_ota_no_fs.csv sums to exactly 4 MB, so the OTA layout now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
    [main.cpp, pins.h]
2026-08-14 updated pcb design to v0.3
    [easy-bee-counter-2026-B_Cu.gbr, easy-bee-counter-2026-B_Mask.gbr, easy-bee-counter-2026-B_Paste.gbr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]
2026-08-14 firmware: fix debounce, MCP validity/health and counter wrap
    Addresses five findings from a code audit of the counting path.
    1. The debounce was not a debounce. It kept only the accepted state plus a
    "last change" timestamp, and refreshed that timestamp on every poll where
    the raw reading still agreed with the accepted state. At the moment of a
    change the elapsed-time test therefore measured the POLL PERIOD, not how
    long the new value had persisted — and with a 5 ms poll against a 3 ms
    threshold the first differing sample was always accepted. One corrupted
    MCP23017 word could move the state machine.
    The debounce now tracks the candidate value separately from the acce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
    [main.cpp]
2026-08-14 Revise the BLE measurement contract to protocol v3
    Three contract-level defects in the measurement characteristic could not be
    fixed on the counter alone -- each needs HiveHub's parser to change in step --
    so they are fixed together as one revision rather than three rounds of
    coordinated deployment.
    * uptime_s: uint16_t -> uint32_t. It clamped at 65535 (18 h 12 min), so an
    always-on counter reported one constant number for its whole deployment and
    could not do the only job the field has: showing an unexpected reset. The
    practical limit is now millis() rolling over at ~49.7 days, not the width.
    * glitches: uint16_t -> uint32_t, still saturating rather than wrapping. A
    noisy device re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
    [ble_link.cpp, main.cpp]
2026-08-19 firmware: add night mode as a bounded sensing suspension (protocol v4)
    The 48 IR emitters are the counter's power budget: 24 series pairs behind
    22 ohm ballast, all lit together for the settle+read window of every 5 ms
    poll — roughly 0.5-1.0 A peak and, at the pulsed sampler's ~35% duty, an
    average an order of magnitude above the ~18 mA the C6 and the three
    expanders draw between them. European honey bees are diurnal (flight needs
    light, and stops below roughly 10 C regardless), so every night that draw
    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
2026-08-19 firmware: pin the platform so the C6 build resolves at all
    The new CI workflow's first run failed with "This board doesn't support
    arduino framework!". Not a regression from night mode — a latent breakage
    this repo had no CI to notice.
    `platform = espressif32` was unpinned, so it resolves to the official
    Espressif platform, which at 7.0.1 still bundles Arduino core 2.0.17. That
    core has no ESP32-C6 Arduino support; C6 support arrived in Arduino-ESP32
    3.x. Anyone running the documented `pio run` on a fresh install has been
    getting that error rather than a firmware image.
    Pin the pioarduino release HiveHub already builds this same chip with
    (55.03.39 = Arduino-ESP32 3.3.9 / ESP-IDF 5.5.4),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
2026-08-19 test: compile idle_state.h against Arduino's macro namespace
    Companion to the HiveHub fix. These host tests build the pure headers
    against a bare compiler, where Arduino's few hundred all-caps macros do not
    exist — so a constant in the shared counter_protocol.h that collides with
    one of them passes every check here and fails only in the firmware build.
    HiveHub hit exactly that with an enumerator named DISABLED meeting
    esp32-hal-gpio.h's `#define DISABLED 0x00`.
    Define the macros that actually bite before the include, so the collision
    surfaces in seconds on a host compiler instead of partway through a
    firmware build.
    Claude-Session: ht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
2026-08-22 Let each of the three emitter banks be switched off individually
    The 2026-08 board puts one IRLB8721 behind each MCP23017, which makes each
    third of the entrance independently switchable. Measured at 3.3 V, one bank
    draws ~0.14 A, two ~0.22 A and three ~0.30 A — roughly 80 mA per bank on top
    of a ~60 mA floor — so for an entrance narrower than 24 gates, or a supply
    that will not carry the full board, this is the coarsest and most effective
    power knob available. It composes with night mode rather than competing with
    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
2026-08-24 Advertise the counter's address in its BLE name
    Every counter advertised the identical local name "BeeCounter", so an apiary
    with several in range produced a scan list of identical rows: picking the right
    one for pairing, or working out which of three on a bench is being flashed,
    meant opening a scanner's detail view and reading addresses.
    The advertised name is now built at boot as "HiveTraffic-AB:12", where the
    suffix is the last two bytes of the counter's own BLE address rendered the way
    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
2026-08-24 fix: keep the hex table out of Arduino's macro namespace
    The name builder used a `static const char HEX[]` lookup table, and Print.h
    defines `HEX` as 16. Every host check passed and the firmware build failed with
    "expected unqualified-id before numeric constant" — the same collision class
    this repo already hit once, where an enumerator named DISABLED met
    The table is now `hex_digits`. Lower case is the actual fix: Arduino's macros
    are all-caps, so a lower-case identifier cannot collide with one no matter
    which of its few hundred macros a future header pulls in.
    test/test_device_name/ grows the macro block test_idle_state.cpp already
    carries, ex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
